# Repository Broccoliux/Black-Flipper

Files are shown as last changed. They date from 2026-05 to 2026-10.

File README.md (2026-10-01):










# FLIPPER BLACK

Flipper black is custom made hacking tool, it can out perfrom flipper Zero in almost every aspect. it have better and larger dsplay and have more power and range then flipper zero.

# Why i built this

I wanted a flipper zero but when i researched about it. i found out that just buying a Flipper Zero is almost useless, to unlock its full power we need to spend more $$, so i decided to build my own with everything in it, no external attachments needed.

# Zine

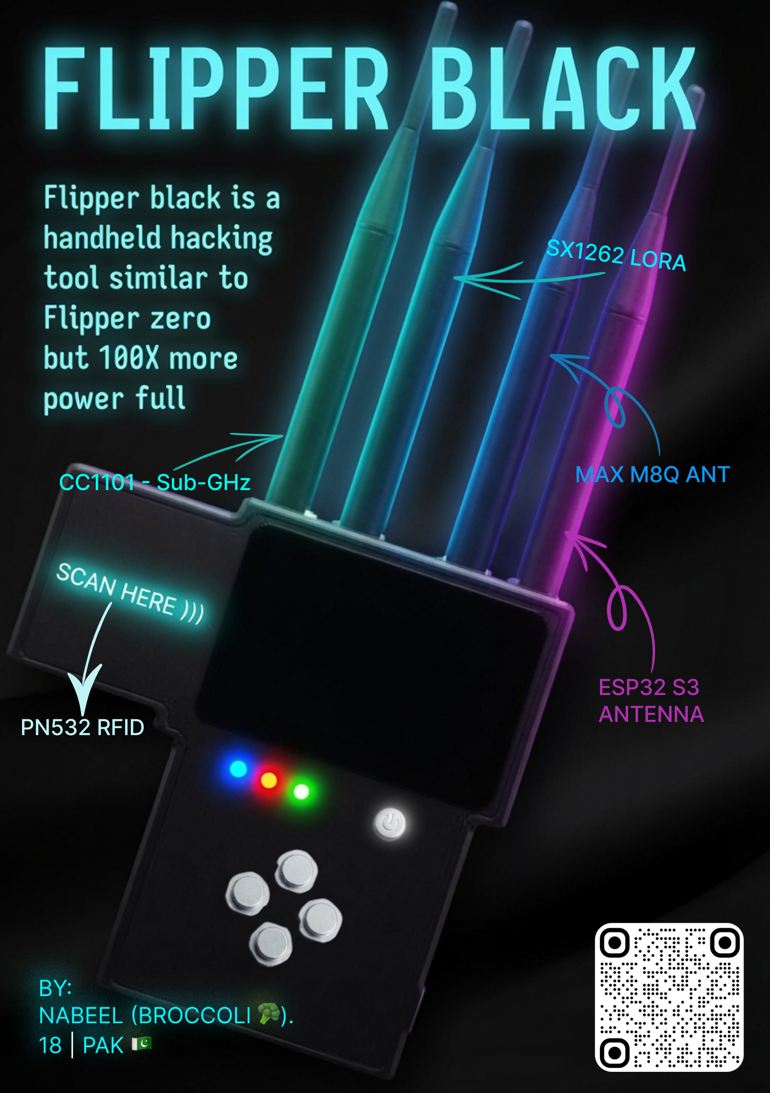
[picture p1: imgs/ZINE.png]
zine Preview


### CAD n Assembly

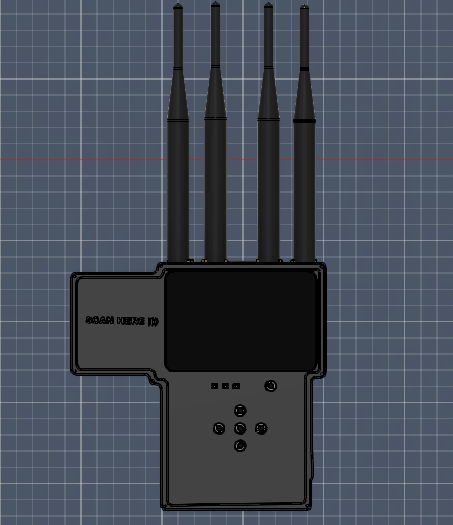
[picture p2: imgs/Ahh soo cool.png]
Assembled Device


### PCB

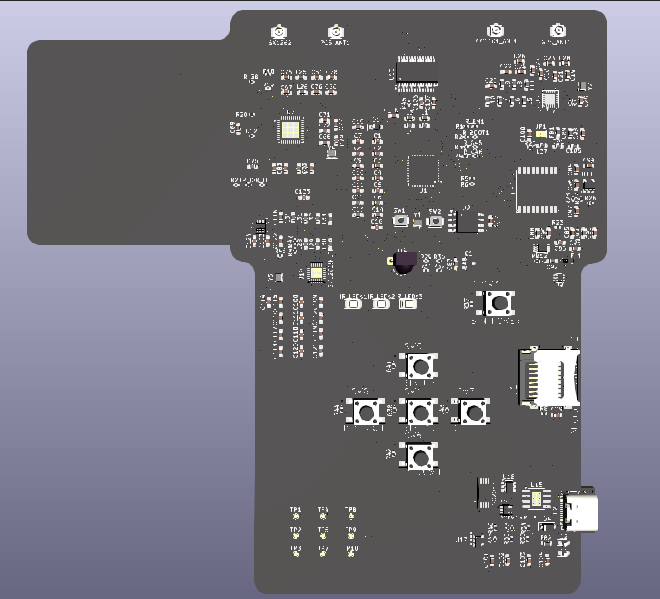
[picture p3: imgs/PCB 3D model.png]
PCB 3D Model


### Assembly

1. place the PCB in the enclosure.
2. secure the PCB with M2 screws.
3. Connect the display to FPC connector.
4. connect the antenna at top.
5. close with top enclosure and secure with screws.

## Features / components

- 4 layer PCB
- only ICs no modules used.
- Wi-Fi 802.11 built in
- BLE 5.0
- CC1101
- PN532
- MAX-M8Q
- Waveshare 3.5" IPS capacitive touchscreen
- W25Q128
- MicroSD
- TP4056
- TLV70018
- TXB0102
- Firmware based on ESP-IDF
- **Estimated BOM Cost:** $280–$350

## Firmware

**Status:** linked as a submodule

- Firmware is maintained in a differnt repository: https://github.com/fussdeek-del/Black-Flipper-firmware
- The firmware repository is included here as a git submodule at `external/firmware`.

To initialize the submodule locally after cloning:

```bash
git clone https://github.com/fussdeek-del/Black-Flipper
cd Black-Flipper
git checkout integrate/firmware-submodule-fix
git submodule update --init --recursive
```

To build the firmware (see the firmware repo):

```bash
cd external/firmware
idf.py build
```

 ### how to replicate

1. Get the gerber zip form repo and order the PCB from JLCPCB.
2. after receiving the PCB flash the firmware.
3. take the .step files from the repo and order the encloure.
4. here u go, u got custom flipper Black.

## Repository Structure
```

```text
Flipper-Black/
├── PCB/                        # KiCad project + Gerbers
├── CAD/                        # Fusion 360 enclosure (.step)
├── flipper black firmware/     # ESP-IDF firmware + architecture
├── Flipper Black guide pdfs/   # Documentation and guides
├── imgs/                       # Photos and renders
├── BOM/                        # Bill of Materials
└── README.md
```

### built by 

***broccoli 🥦***

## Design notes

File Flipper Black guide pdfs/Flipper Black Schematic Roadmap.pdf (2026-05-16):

# FLIPPER BLACK

# Complete Schematic Roadmap

This guide walks you through building the entire Flipper Black schematic in KiCad, chip by chip, step by step. Every connection is explained — what connects to what, why, and what label to use. Follow every chip section in order. Do not skip ahead.

WARNING: Web-verified against Espressif Hardware Design Guidelines (April 2026), CC1101 datasheet (TI), and SX1276 datasheet (Semtech). Always cross-check pin numbers against your exact chip datasheet before placing wires.

# Build order

### 1. ESP32-S3 — main MCU (start here)

### 2. W25Q128 — SPI flash (do immediately after MCU)

### 3. CC1101 — sub-GHz radio + RF matching network

### 4. SX1276 — LoRa transceiver + RF matching network

### 5. PN532 — NFC / RFID controller

### 6. MAX-M8Q — GPS + TLV70018 LDO + TXB0102 level shifter

### 7. Display + touch controller

### 8. IR TX / RX

### 9. Power system (TP4056 + DW01A + AP2112K + battery)

### 10. Buttons, test points, USB-C connector

CHIP 1 | ESP32-S3 | Main MCU — do this chip completely before anything else

The ESP32-S3 is the brain. Every other chip connects to it. You must finish this chip completely — every power pin, every decoupling cap, every strapping pin, the crystal, the flash SPI pins, the USB pins, and all net labels. Only then move to Chip 2.

## 1A — Power pins

The ESP32-S3 has multiple VDD pins. Each one needs its own 100nF decoupling capacitor placed directly on it. This is verified from the official Espressif Hardware Design Guidelines (April 2026).

Pin name | Pin number | What to connect | Cap required
VDD3P3_CPU | 46 | +3V3 power symbol | 100nF to GND
VDD3P3_RTC | 20 | +3V3 power symbol | 100nF to GND
VDD3P3 (analog) | 2, 3 | +3V3 power symbol | 100nF + 1uF + 10uF to GND — RF transmit causes current spikes
VDDA | 55, 56 | +3V3 power symbol | 100nF to GND each pin
VDD_SPI | 29 | +3V3 power symbol | 100nF + 1uF to GND — powers W25Q128 flash
GND | All GND pins | GND symbol | No cap needed
Thermal pad (bottom) | EP | GND symbol | Connect to large GND pad with minimum 9 vias in PCB layout

CRITICAL: Add a 10uF capacitor on VDD3P3 (pins 2 and 3). When ESP32-S3 transmits WiFi signals it draws sudden current spikes that collapse the power rail. The 10uF bulk cap prevents this. Verified from Espressif guidelines.

## 1B — Crystal (40 MHz — mandatory)

ESP32-S3 requires an external 40 MHz crystal. This is not optional. Without it the chip will not boot. Connect between XTAL_P and XTAL_N pins.

ESP32-S3 pin | Connect to | Value | Notes
XTAL_P (XIN) | Crystal pin 1 + load cap C1 to GND | Crystal: 40MHz SMD 3225 | Use NP0/C0G dielectric for load caps — NOT X7R or Y5V
XTAL_N (XOUT) | Crystal pin 2 + load cap C2 to GND | Crystal: 40MHz SMD 3225 | Load cap value matches crystal datasheet CL spec (typically 10pF)
XTAL_P trace | Series inductor R4 between XIN and crystal | 24nH inductor (initial value) | Reduces crystal harmonics affecting RF. Espressif recommends starting here.

TIP: Crystal load cap formula from Espressif: CL = (C1 x C2)/(C1+C2) + Cstray. If your crystal CL is 10pF and Cstray is ~2pF, use 22pF load caps. Check your crystal's datasheet CL value.

## 1C — Strapping pins (boot configuration)

Strapping pins are read at power-on to decide how the chip boots. Get these wrong and the chip won't start or will always enter download mode. These are verified from Espressif Hardware Design Guidelines.

GPIO | Net label | Connection | Why
GPIO0 | BOOT_BTN | 10k pull-up to +3V3. Tactile button to GND. | HIGH = normal boot. LOW = download/flash mode. Button lets you enter flash mode.
GPIO45 | GPIO45_STRAP | 10k pull-down to GND (resistor to GND). | Controls VDD_SPI voltage. LOW = 3.3V for W25Q128 flash (default needed).
GPIO46 | GPIO46_STRAP | 10k pull-down to GND (resistor to GND). | Must be LOW at boot. Do not leave floating.
CHIP_PU (EN) | EN_BTN | 10k pull-up to +3V3. Tactile button to GND. RC filter: 1uF cap to GND on this pin. | Enables chip when HIGH. Button pulls LOW to reset. RC filter prevents false resets.

WARNING: Do not add high-value capacitors on GPIO0. A large cap on GPIO0 keeps it LOW too long at startup, causing the chip to enter download mode every boot. The RC filter goes on CHIP_PU (EN) only, not on GPIO0.

## 1D — SPI net labels (signal pins to other chips)

These GPIO pins connect to other chips via net labels. Place the label on the GPIO pin. The matching label goes on the destination chip pin. This is how chips talk to each other without drawing wires across the sheet.

GPIO | Net label | Connects to | Direction
GPIO11 | SPI2_MOSI | CC1101 SI, PN532 MOSI (shared bus) | ESP32 sends data OUT
GPIO12 | SPI2_SCK | CC1101 SCLK, PN532 SCK (shared bus) | ESP32 sends clock OUT
GPIO13 | SPI2_MISO | CC1101 SO, PN532 MISO (shared bus) | ESP32 receives data IN
GPIO10 | SPI2_CS_CC1101 | CC1101 CSn only | ESP32 selects CC1101
GPIO9 | SPI2_CS_PN532 | PN532 NSS only | ESP32 selects PN532
GPIO35 | SPI3_MOSI | SX1276 MOSI, W25Q128 DI (shared bus) | ESP32 sends data OUT
GPIO36 | SPI3_SCK | SX1276 SCK, W25Q128 CLK (shared bus) | ESP32 sends clock OUT
GPIO37 | SPI3_MISO | SX1276 MISO, W25Q128 DO (shared bus) | ESP32 receives data IN
GPIO34 | SPI3_CS_SX1276 | SX1276 NSS only | ESP32 selects SX1276
GPIO33 | SPI3_CS_FLASH | W25Q128 /CS only | ESP32 selects flash
GPIO43 | ESP_UART_TX | TXB0102 level shifter B2 | GPS config commands OUT (add 100 ohm series resistor — boot conflict)
GPIO44 | ESP_UART_RX | TXB0102 level shifter B1 | GPS NMEA data IN
GPIO4 | CC1101_GDO0 | RF switch control + CC1101 GDO0 | TX/RX state signal from CC1101

GPIO | Net label | Connects to | Direction
GPIO5 | CC1101_GDO2 | CC1101 GDO2 | Packet interrupt from CC1101
GPIO21 | SX1276_DIO0 | SX1276 DIO0 | TX done / RX done interrupt from SX1276
GPIO47 | SX1276_RST | SX1276 RESET | ESP32 resets SX1276 — add 10k pull-up to +3V3
GPIO6 | PN532_IRQ | PN532 IRQ | Card detected interrupt from PN532
GPIO1 | I2C_SDA | Touch controller SDA | Bidirectional — add 4.7k pull-up to +3V3
GPIO2 | I2C_SCL | Touch controller SCL | Clock out — add 4.7k pull-up to +3V3
GPIO3 | TOUCH_IRQ | Touch controller IRQ | Touch interrupt IN
GPIO38 | IR_TX | NPN transistor base for IR LED | PWM output for IR transmission
GPIO39 | IR_RX | TSOP38238 IR receiver output | IR signal IN
GPIO7 | BATT_ADC | Voltage divider from battery | Analog IN — battery level monitoring
GPIO19 | USB_DN | USB-C connector D- | Fixed USB OTG pin — cannot change
GPIO20 | USB_DP | USB-C connector D+ | Fixed USB OTG pin — cannot change

TIP: GPIO33-37 are only available if you are NOT using octal PSRAM. Since Flipper Black uses external W25Q128 flash with no PSRAM, these GPIOs are free for SPI3.

CHIP 2 | W25Q128 | 16MB SPI Flash — do immediately after ESP32-S3

The W25Q128 is the firmware storage chip. It connects to ESP32-S3 via SPI3. You placed SPI3 net labels on ESP32-S3 already. Now you place matching labels on the W25Q128 pins.

## Pin connections

W25Q128 pin | Pin name | Net label | Notes
1 | /CS | SPI3_CS_FLASH | Active LOW. Add 10k pull-up to +3V3 — keeps chip deselected at power-on
2 | DO (MISO) | SPI3_MISO | Data out from flash to ESP32
3 | /WP | Tie to +3V3 via 10k pull-up | Write protect — pull HIGH to disable write protection
4 | GND | GND | Ground
5 | DI (MOSI) | SPI3_MOSI | Data in from ESP32 to flash
6 | CLK | SPI3_SCK | SPI clock from ESP32
7 | /HOLD | Tie to +3V3 via 10k pull-up | Hold pin — pull HIGH to disable hold function
8 | VCC | +3V3 | 100nF + 1uF decoupling caps to GND

TIP: After soldering, run 'esptool.py flash_id' to verify. Correct response: Manufacturer 0xEF, Device 0x4018. If you see 0xFF, there is a bad solder joint on one of the signal pins.

CHIP 3 | CC1101 | Sub-GHz Radio — includes RF matching network

The CC1101 is the most complex chip in terms of external components. It has a digital side (SPI interface to ESP32-S3) and an RF side (antenna matching network). Do the digital side first, then the RF side.

## 3A — Digital side (SPI + power)

CC1101 pin | Pin name | Net label / connection | Notes
1 | SCLK | SPI2_SCK | SPI clock from ESP32-S3
2 | SO (GDO1) | SPI2_MISO | SPI data out to ESP32-S3
3 | GDO2 | CC1101_GDO2 | Optional interrupt — connect to GPIO5. Add 10k pull-up to +3V3.
4 | DVDD | Leave isolated — connect only to C51 | DO NOT connect to your 3.3V rail. This is a regulated output FROM the chip. Connecting 3.3V here destroys it.
5 | DCOUPL | 100nF cap to GND only | Decoupling for internal regulator. No connection to power rail.
6 | GDO0 / CSn | GDO0: CC1101_GDO0 to GPIO4. CSn: SPI2_CS_CC1101 | Two separate pins. GDO0 is the TX/RX state indicator. CSn is chip select.
7 | GND | GND | Ground
8 | XOSC_Q1 | 26MHz crystal pin 1 + 15pF cap to GND | CC1101 needs 26MHz — NOT 40MHz
9 | AVDD | See power below | Analog VDD
10 | XOSC_Q2 | 26MHz crystal pin 2 + 15pF cap to GND
11 | AVDD | See power below
18 | GND | GND | Die attach pad — connect to GND with multiple vias
19 | GND | GND
20 | SI | SPI2_MOSI | SPI data in from ESP32-S3

### Power pins — CC1101 has 4 AVDD pins

Pin | Name | Connection | Decoupling
9 | AVDD | +3V3 | 100nF to GND
11 | AVDD | +3V3 | 100nF to GND
14 | AVDD | +3V3 | 100nF to GND
15 | AVDD | +3V3 | 100nF + 1uF to GND (this is the main RF power pin)

Also add a ferrite bead or small inductor (R171 in the datasheet schematic) in series with the power supply trace feeding all AVDD pins. This filters switching noise from entering the chip. Use a 600 ohm @ 100MHz ferrite bead.

## 3B — RF matching network (copy from datasheet)

The RF matching network sits between the CC1101's RF_P and RF_N pins and the antenna. Its job is to match the chip's output impedance to 50 ohms (the antenna standard). Use values from TI's datasheet Table 5 and DN013. Values differ per frequency band.

### Values for 433 MHz (ISM band — recommended for Flipper Black for maximum compatibility)

Component | Value | Location in circuit | Notes
L121 | 270nH | RF_P to balun | Multilayer OK for 433MHz
L122 | 270nH | RF_N to balun | Multilayer OK for 433MHz
L131 | 270nH | Balun inductor
L132 | 270nH | Balun inductor
C121 | 56pF | Matching cap | NPO/C0G dielectric — mandatory for RF
C122 | 56pF | Matching cap | NPO/C0G
C123 | 10pF | Matching cap | NPO/C0G
C124 | 12pF | Matching cap | NPO/C0G
C131 | 100nF | AVDD decoupling in RF section | +3V3 to GND, close to RF section
L123 | 39nH | Final matching inductor | Wire-wound for 433MHz
L124 | 39nH | Final matching inductor | Wire-wound
C125 | 100pF | DC blocking cap to antenna | Blocks DC, passes RF signal to antenna

### Values for 868 MHz (if you choose this band instead)

Component | Value | Notes
L121 | 5.6nH | Wire-wound required for 868MHz — not multilayer
L122 | 5.6nH | Wire-wound required
C121 | Not placed | Remove this component for 868MHz
C122 | Not placed | Remove this component for 868MHz
C123 | 5.6pF | NPO/C0G
C124 | 2.7pF | NPO/C0G
L131 | 8.2nH | Wire-wound balun
L132 | 8.2nH | Wire-wound balun
C131 | 100nF | Decoupling
C125 | 100pF | DC blocking to antenna

TIP: Use TI SmartRF Studio 7 (free download at ti.com/tool/SMARTRFSTUDIO) to generate exact CC1101 register values for your chosen frequency. Copy the output directly into firmware. Never calculate manually.

CRITICAL: Never use multilayer inductors for 868MHz or 915MHz RF matching. Their Q factor is too low at high frequency. Use wire-wound inductors (Murata LQW series or similar). For 433MHz multilayer is acceptable.

CHIP 4 | SX1276 | LoRa Transceiver — includes RF matching network

SX1276 is your LoRa radio. It has a 28-pin QFN package. Connect SPI3 from ESP32-S3, plus dedicated interrupt and reset pins. The RF output goes through a simple matching network to a U.FL connector or PCB trace antenna.

## 4A — SPI and control pins

SX1276 pin | Pin name | Net label / connection | Notes
1 | VDD_RXBPF | 100nF to GND | Internal LNA supply — decouple to GND only
2 | VDD_DCDC | Not connected (no connect marker) | Internal DC-DC — leave open unless using DC-DC mode
3 | VDD | + 3V3 | 100nF + 10uF to GND
5 | RFIO | RF output — to matching network | 50 ohm trace to matching network then U.FL
10 | NSS | SPI3_CS_SX1276 | Chip select. 10k pull-up to +3V3
11 | SCK | SPI3_SCK | SPI clock from ESP32
12 | MOSI | SPI3_MOSI | SPI data from ESP32
13 | MISO | SPI3_MISO | SPI data to ESP32
14 | RESET | SX1276_RST | Active LOW reset from GPIO47. 10k pull-up to +3V3.
15 | DIO0 | SX1276_DIO0 | TX done/RX done interrupt to GPIO21. MUST connect — do not float.
16 | DIO1 | Optional — connect to free GPIO or add no-connect marker | RX timeout interrupt
17 | DIO2 | No connect marker
18 | DIO3 | No connect marker
19 | DIO4 | No connect marker
20 | DIO5 | No connect marker
21 | GND | GND | Ground
28 | XTAL_2 | Crystal pin 2 + 10pF to GND | 32MHz crystal for SX1276
27 | XTAL_1 | Crystal pin 1 + 10pF to GND | 32MHz — different from ESP32's 40MHz

## 4B — RF matching network for 868 MHz

SX1276 RFIO pin connects to a simple pi-network matching circuit then to your antenna connector. The datasheet AN1200.13 provides these values.

Component | Value | Placement
L1 (RF choke) | 47nH | Between VDD and RFIO — blocks DC from antenna path

Component | Value | Placement
C1 | 10pF NPO | RFIO to GND — part of pi matching
C2 | Not placed (open) | Shunt cap — tune after testing
C3 (DC block) | 100pF NPO | Series between matching network and antenna
Antenna connector | U.FL SMD | 50 ohm impedance — route 50 ohm trace to here

TIP: Reference the Semtech SX1276 application note AN1200.13 (available at semtech.com) for the exact recommended matching network. For initial build just use the minimal circuit above — it works well enough to test range.

CHIP 5 | PN532 | NFC / RFID Controller

PN532 connects to SPI2 (same bus as CC1101, different CS pin). Interface mode is set permanently by two strapping pins using 0-ohm resistors — this is set before the board is made and cannot be changed in firmware.

## 5A — Interface mode selection (do this first)

PN532 has three interface modes. You must choose SPI mode. Set it by placing 0-ohm resistors on HSU0 and HSU1 pins. These resistors tie the pins to the correct voltage permanently.

Pin | Name | Connection for SPI mode | How to place it
HSU1 | Interface select 1 | Tie to GND via 0-ohm resistor | Place 0-ohm 0402 resistor between HSU1 and GND pad
HSU0 | Interface select 0 | Tie to +3V3 via 0-ohm resistor | Place 0-ohm 0402 resistor between HSU0 and +3V3 pad

WARNING: Do not hardwire HSU0/HSU1 directly to copper. Use 0-ohm resistors so you can change mode by reworking the resistors if needed. This was flagged in the improvement list.

## 5B — Pin connections

PN532 pin | Pin name | Net label / connection | Notes
1 | TXD / MISO | SPI2_MISO | SPI data out to ESP32 in SPI mode
2 | RXD / MOSI | SPI2_MOSI | SPI data in from ESP32 in SPI mode
3 | SCK | SPI2_SCK | SPI clock
4 | NSS | SPI2_CS_PN532 | Chip select. 10k pull-up to +3V3.
8 | IRQ | PN532_IRQ to GPIO6 | Interrupt output — card detected. 10k pull-up to +3V3.
VDD | VDD | +3V3 | 100nF + 1uF to GND
RSTPDN | Reset | 10k pull-up to +3V3. Optional GPIO for hard reset. | Active LOW reset
SVDD | SVDD | +3V3 | 100nF to GND — separate supply for RFID analog section
GND | GND | GND

## 5C — NFC antenna coil

PN532 needs an external PCB coil antenna. This is a rectangular spiral trace on your PCB, not a component you buy. The datasheet application note AN10609 gives the exact coil dimensions and tuning capacitor values. Draw it as a symbol in KiCad and connect pins LXIN and LXOUT to it via matching capacitors.

PN532 pin | Connect to
LXIN | NFC antenna coil pin 1 via tuning cap (C = 22pF typical, tune per AN10609)
LXOUT | NFC antenna coil pin 2 via tuning cap

## CHIP 6 MAX-M8Q + TLV70018 + TXB0102

GPS subsystem — three components treated as one

The GPS subsystem has three parts that must be designed together: the MAX-M8Q GPS chip (runs at 1.8V), the TLV70018 LDO (generates the 1.8V rail), and the TXB0102 level shifter (converts 1.8V UART to 3.3V for ESP32-S3). Do all three on the same schematic sheet.

## 6A — TLV70018 (1.8V LDO) — place this first

TLV70018 pin | Connection | Value
IN | +3V3 power symbol | 10uF + 100nF to GND on input
OUT | +1V8 power symbol — new power rail | 10uF + 100nF to GND on output
EN | Tie to IN (+3V3) via 100k pull-up | Always enabled — or connect to ESP32 GPIO for software control
GND | GND

CRITICAL: MAX-M8Q absolute maximum voltage is 1.9V. If you accidentally connect +3V3 to its VCC pin it is destroyed instantly and permanently. Label the 1.8V rail clearly as +1V8 so it cannot be confused with +3V3.

## 6B — MAX-M8Q GPS pin connections

MAX-M8Q pin | Pin name | Connection | Notes
VCC | +1V8 rail | 100nF + 1uF to GND — from TLV70018 output | NOT 3.3V — 1.8V only
VCC_IO | +1V8 rail | 100nF to GND separately | IO voltage — must match UART logic level
GND | GND | Multiple vias — short path
V_BCKP | Supercap (100mF) or coin cell (3V) | Maintains almanac between power cycles | Without this every startup is a 60s cold start. With it: 1s warm start.
TXD1 | GPS_TX_1V8 net label | Goes to TXB0102 A1 pin (1.8V side) | GPS sends NMEA sentences here
RXD1 | GPS_RX_1V8 net label | Goes to TXB0102 A2 pin (1.8V side) | GPS receives UBX config commands here
TIMEPULSE | Optional — no connect or GPIO | 1 pulse per second when satellite locked
RESET_N | 10k pull-up to +1V8 | Add optional GPIO for software reset | Active LOW
RF_IN | 50 ohm trace to U.FL connector | Passive ceramic patch antenna | Keep trace short. No ground pour under antenna area.

## 6C — TXB0102 level shifter pin connections

TXB0102 translates between 1.8V (GPS side) and 3.3V (ESP32 side). It has an A-side (1.8V) and a B-side (3.3V). OE pin must be tied HIGH to 3.3V — if it floats the chip outputs nothing.

TXB0102 pin | Connection | Notes
VCCA | +1V8 | 1.8V supply for GPS side. 100nF to GND.
VCCB | +3V3 | 3.3V supply for ESP32 side. 100nF to GND.
OE | Tie directly to VCCB (+3V3) | CRITICAL — must be HIGH. Floating OE = no data passes through.
A1 (1.8V side) | GPS_TX_1V8 (from MAX-M8Q TXD1) | GPS sends here
A2 (1.8V side) | GPS_RX_1V8 (to MAX-M8Q RXD1) | GPS receives here
B1 (3.3V side) | ESP_UART_RX (GPIO44 net label) | Translated signal to ESP32
B2 (3.3V side) | ESP_UART_TX (GPIO43 net label) | Translated signal from ESP32
GND | GND

WARNING: GPIO43 on ESP32-S3 is the default boot serial console TX pin. Add a 100 ohm series resistor between GPIO43 and the TXB0102 B2 pin. This prevents the boot console from fighting the GPS UART at startup.

## CHIP 7 Display + Touch Controller

3.5 inch IPS color touchscreen

The display uses SPI for pixel data and I2C for touch input. The exact pin names depend on your specific display module. Common controllers are ILI9488 or ST7796S for the display, FT6336 or CST816 for touch. Check your display's datasheet.

Signal | Net label | ESP32 GPIO | Notes
Display SPI MOSI | DISP_MOSI | GPIO15 | Data from ESP32 to display
Display SPI SCK | DISP_SCK | GPIO16 | Clock
Display CS | DISP_CS | GPIO17 | Chip select. 10k pull-up to +3V3.
Display DC | DISP_DC | GPIO18 | Data/Command select — HIGH=data, LOW=command
Display RST | DISP_RST | GPIO8 | Active LOW reset. 10k pull-up to +3V3.
Display VCC | +3V3 | — | 100nF + 10uF to GND
Touch SDA | I2C_SDA | GPIO1 | 4.7k pull-up to +3V3
Touch SCL | I2C_SCL | GPIO2 | 4.7k pull-up to +3V3
Touch IRQ | TOUCH_IRQ | GPIO3 | Interrupt — touch detected. 10k pull-up to +3V3.
Touch VCC | +3V3 | — | 100nF to GND
Backlight | Connect via NPN transistor or MOSFET to GPIO | — | PWM brightness control via transistor — do not connect LED directly to GPIO

CHIP 8 | IR TX / RX | Infrared transmitter and receiver

IR TX uses a high-power IR LED driven by an NPN transistor (2N2222 or MMBT2222 SMD). The transistor is needed because GPIO can only source 40mA — the IR LED needs more for good range. IR RX uses a demodulating receiver IC (TSOP38238) that handles filtering and demodulation automatically.

Component | Pin | Net label / connection | Notes
NPN transistor (MMBT2222) | Base | IR_TX (GPIO38) via 100 ohm resistor | Resistor limits base current
NPN transistor | Collector | IR LED array anode | Up to 3 IR LEDs in series
NPN transistor | Emitter | GND
IR LED array | Anode | Transistor collector | High-power 940nm IR LEDs (TSAL6400 or similar)
IR LED array | Cathode | GND | 33 ohm current limiting resistor in series
TSOP38238 receiver | OUT | IR_RX (GPIO39) | Output is demodulated IR signal
TSOP38238 | VCC | +3V3 | 100nF + 10uF to GND — datasheet requires good decoupling here
TSOP38238 | GND | GND

CHIP 9 | Power System | TP4056 + DW01A + AP2112K + battery connector

The power system has four parts: the TP4056 charges the battery from USB-C. The DW01A protects against overcharge, overdischarge, and short circuit. The AP2112K converts battery voltage to clean 3.3V. Design these in order.

## 9A — TP4056 battery charger

TP4056 pin | Connection | Notes
VCC | VBUS (+5V from USB-C) | 100nF to GND
GND | GND
PROG | Resistor to GND | Sets charge current. 1.2kohm = 1A charge current.
TEMP | 10k pull-up to VCC | No thermistor — just pull up
CHRG | LED + resistor to GND (optional) | Charge indicator LED — shows when charging
STDBY | LED + resistor to GND (optional) | Standby indicator LED — shows charge complete
BAT | Battery positive via DW01A | Output to battery — goes through DW01A first

## 9B — DW01A protection IC + FS8205 dual MOSFET

DW01A works together with a dual N-channel MOSFET (FS8205A) to physically disconnect the battery under fault conditions. They must be used together.

DW01A pin | Connection
VDD | Battery positive (after TP4056 BAT pin)
GND / CS | Battery negative + current sense resistor to GND
OC | FS8205A gate 1 — controls overdischarge cutoff
OD | FS8205A gate 2 — controls overcharge cutoff

## 9C — AP2112K-3.3 LDO regulator

AP2112K pin | Connection | Notes
VIN | Battery positive (from DW01A protected output) | 1uF + 10uF to GND on input
GND | GND
EN | Tie to VIN via 100k pull-up | Always enabled. Or connect to GPIO for software power control.
VOUT | +3V3 power rail | 10uF + 100nF to GND on output. This feeds every chip on the board.
VOUT (bulk) | Add 100uF electrolytic to GND | Handles large transient current spikes from WiFi and RF TX

## 9D — Battery connector

Connector pin | Connection
Pin 1 (positive) | TP4056 BAT and DW01A VDD
Pin 2 (negative) | GND via DW01A / FS8205A current sense path

TIP: Use a JST-PH 2.0mm 2-pin connector for the battery. This is the standard for 18650 and LiPo cells. Orient it on the PCB so polarity is obvious — mark + and - on the silkscreen.

CHIP
10

## Buttons + Test Points + USB-C

Final connections

## 10A — BOOT and EN buttons

Both buttons must be accessible from outside the aluminum enclosure without disassembly. Route them to pinhole buttons in the enclosure wall or to a header accessible from outside.

Button | Connects between | Net label | Notes
BOOT button | GPIO0 and GND | BOOT_BTN | GPIO0 already has 10k pull-up from Chip 1 strapping pins
EN (reset) button | CHIP_PU and GND | EN_BTN | CHIP_PU already has 10k pull-up and 1uF RC filter from Chip 1

## 10B — Test points (mandatory for debugging raw chips)

Test points are bare 1mm copper pads with no solder mask. You probe them with a scope or multimeter. Add one on every critical net. Raw QFN chips at 0.5mm pitch are impossible to probe directly.

Test point | Net to connect | Why
TP1 | SPI2_MOSI | Debug CC1101 and PN532 data
TP2 | SPI2_SCK | Debug SPI2 clock
TP3 | SPI2_MISO | Debug SPI2 response
TP4 | SPI3_MOSI | Debug SX1276 and flash data
TP5 | SPI3_SCK | Debug SPI3 clock
TP6 | ESP_UART_TX | Debug GPS UART output
TP7 | ESP_UART_RX | Debug GPS NMEA input
TP8 | +3V3 | Probe main power rail
TP9 | +1V8 | Probe GPS power rail
TP10 | GND | Reference probe point

## 10C — USB-C connector

USB-C pin | Connection | Notes
VBUS | VBUS rail to TP4056 VCC | Add ESD protection diode (USBLC6-2SC6) on VBUS — protects from USB spikes
D+ | USB_DP (GPIO20) | Fixed USB OTG pin on ESP32-S3
D- | USB_DN (GPIO19) | Fixed USB OTG pin on ESP32-S3
CC1, CC2 | 5.1k resistors to GND each | Required for USB-C power negotiation — without these chargers may not provide power
GND | GND | Shield and signal ground

## Final checklist before moving to PCB layout

Check | What to verify
ERC clean | Run Inspect > Electrical Rules Check. Zero errors. All warnings reviewed and justified.
Every VCC pin has decoupling | Open each chip symbol. Confirm 100nF on every VCC pin.
Every CS pin has pull-up | 10k pull-up to +3V3 on: CC1101 CSn, PN532 NSS, SX1276 NSS, W25Q128 /CS
Strapping pins correct | GPIO0 pull-up + button. GPIO45 pull-down. GPIO46 pull-down. EN pull-up + RC + button.
PN532 HSU pins set | HSU1 to GND via 0-ohm. HSU0 to +3V3 via 0-ohm.
TXB0102 OE pin HIGH | OE tied directly to VCCB (3.3V). Not floating.
MAX-M8Q on 1.8V only | +1V8 symbol on MAX-M8Q VCC and VCC_IO. Never +3V3.
Crystal values correct | ESP32-S3: 40MHz. CC1101: 26MHz. SX1276: 32MHz. All different.
No connect markers placed | Every intentionally unused pin has an X marker
Net labels consistent | SPI2_MOSI on ESP32-S3 GPIO11 matches SPI2_MOSI on CC1101 SI exactly — same spelling, same case
All footprints assigned | Tools > Assign Footprints — no components with missing footprint

Flipper Black Schematic Roadmap · Web-verified May 2026 · For personal use only

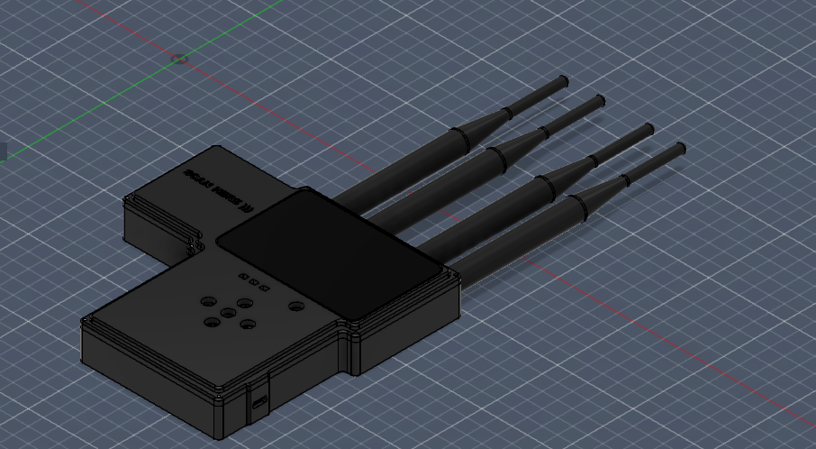
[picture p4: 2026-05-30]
imgs/final design.png

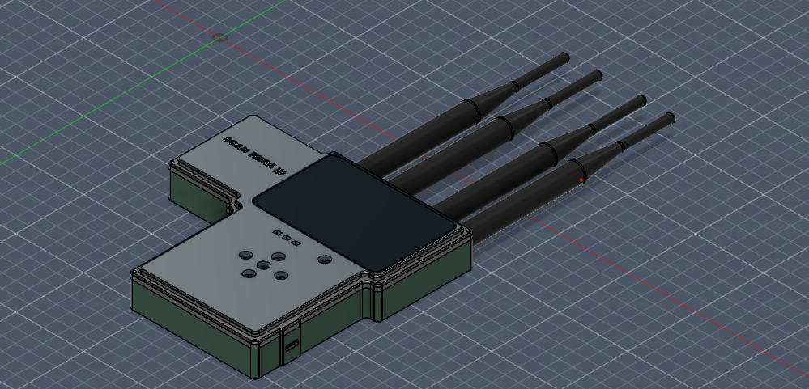
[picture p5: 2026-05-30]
imgs/RAW design.png

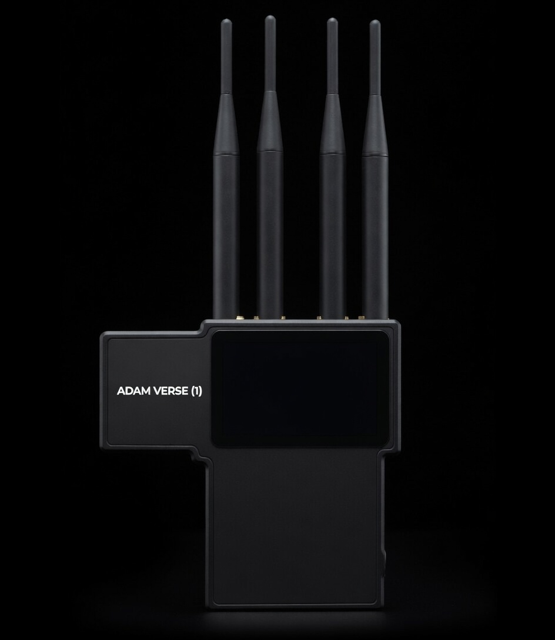
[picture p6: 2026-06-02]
imgs/polished.jpg

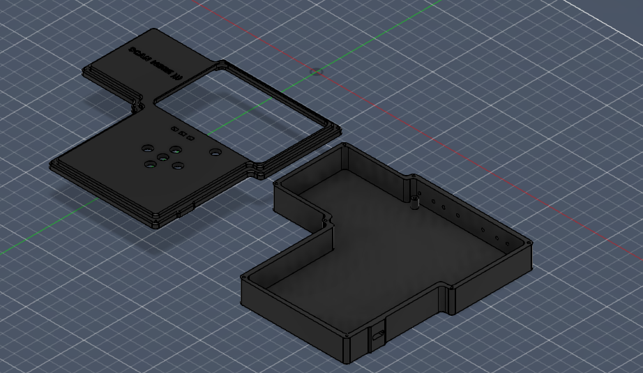
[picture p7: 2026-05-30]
imgs/both bodies.png

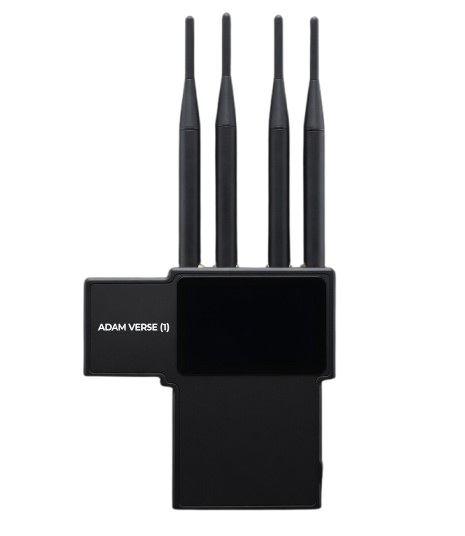
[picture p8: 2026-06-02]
imgs/removed BG.png

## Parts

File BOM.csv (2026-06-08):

Reference | Qty | Value | link | cost | min Qty can buy | Total
C1,C2,C6,C7,C8,C17,C18,C67,C68,C69,C70,C71,C75,C84,C86,C87,C94,C96,C97,C98,C99,C100,C107,C109,C113,C121 | 26 | 100nf | https://www.aliexpress.com/item/32371454429.html | $1.5 | 100
C3,C16,C101 | 3 | 0.1uf | https://www.aliexpress.com/item/1005005653862475.html | $1.5 | 100
C4,C95,C102,C103,C104,C106 | 6 | 10uf | https://www.aliexpress.com/item/1005005653862475.html | $2 | 100
C5,C9,C72,C85,C108,C_EN1 | 5 | 1uf | https://www.aliexpress.com/item/1005007137284660.html | $1 | 100
C10,C11,C19,C20,C21,C22,C23,C24,C28 | 9 | 18pf | https://www.aliexpress.com/item/1005007137284660.html | $1 | 100
C12 | 1 | 1.8pf | https://www.aliexpress.com/item/1005007137284660.htmll | $1 | 100
C13 | 1 | 1.2pf | https://www.aliexpress.com/item/1005007137284660.html | $1 | 100
C14,C25 | 2 | 1.0pf | https://www.aliexpress.com/item/1005007137284660.html | $1 | 100
C15,C26,C27 | 3 | 1.5pf | https://www.aliexpress.com/item/1005007137284660.html | $1 | 100
C74,C78,C80,C92,C119,C73 | 6 | 22pf | https://www.aliexpress.com/item/1005007137284660.html | $1 | 100
C76,C77,C79,C81 | 4 | 220pf | https://www.aliexpress.com/item/1005007137284660.html | $1 | 100
C82,C91,C116,C122 | 4 | 1nf | https://www.aliexpress.com/item/1005007137284660.html | $1 | 100
C83,C105 | 2 | 100pf | https://www.aliexpress.com/item/1005007137284660.html | $1 | 100
C88 | 1 | 47pf | https://www.aliexpress.com/item/1005007137284660.html | $1 | 100
C89 | 1 | 10pf | https://www.aliexpress.com/item/1005007137284660.html | $1 | 100
C90,C93 | 2 | 10nf | https://www.aliexpress.com/item/1005007137284660.html | $1 | 100
C110 | 1 | 470nf | https://www.aliexpress.com/item/1005007137284660.html | $1 | 100
C111,C112,C118,C120,C123 | 5 | 10pf | https://www.aliexpress.com/item/1005007137284660.html | $1 | 100
C114 | 1 | 6.8pf | https://www.aliexpress.com/item/1005007137284660.html | $1 | 100
C115,C125 | 2 | 8.2pf | https://www.aliexpress.com/item/1005007137284660.html | $1 | 100
C117,C124 | 2 | 5.66pf | https://www.aliexpress.com/item/1005007137284660.html | $1 | 100
CC1101_ANT1,GPS_ANT1,PCB_ANT1,SX1262_ANT (U.FL) | 4 | 50ohm | https://www.aliexpress.com/item/1005010015902109.html | $5 | 4
D1 | 1 | TPESD5V0L2 | https://jlcpcb.com/partdetail/TECHPUBLIC-TPMG85XP/C52817258 | $1 | 10
D2,D3 | 2 | LED | https://www.aliexpress.com/item/1005006207219959.html | $3.5 | 200
D4 | 1 | MBR1020VL | https://www.lcsc.com/product-detail/C191986.html | $0.93 | 10
FB1,FB2 | 2 | BLM21PG221SN1D | https://www.lcsc.com/product-detail/C85840.html | $0.92 | 20
FL1 | 1 | SAFFB1G58KA0F0A | https://www.lcsc.com/product-image/C91647.html | $1 | 10
IR_LEDs1,IR_LEDs2,IR_LEDs3 | 3 | 940nm | https://www.aliexpress.com/item/1005003330154455.html | $5 | 20
J2 | 1 | DISP_3.5_WAVESHARE | https://www.aliexpress.com/item/1005008868165133.html | $23 | 1
L1 | 1 | 2nH 500mA | https://jlcpcb.com/partdetail/Sunlord-SDWL1608C24NJSTFM01/C408735 | $0.3 | 10
L2 | 1 | 24nH | https://www.aliexpress.com/item/1005003077524611.html | $2.7 | 50
L3,L4 | 2 | 2.7nH | https://www.aliexpress.com/item/1005003077524611.html | $2.7 | 50
L5,L6,L7,L8,L32 | 5 | 27nH | https://www.aliexpress.com/item/1005003077524611.html | $2.7 | 50
L9,L10 | 2 | 47nH | https://www.aliexpress.com/item/1005003077524611.html | $2.7 | 50
L11 | 1 | 23nH | https://www.aliexpress.com/item/1005003077524611.html | $2.7 | 50
L25,L26 | 2 | 220nH | https://www.aliexpress.com/item/1005003077524611.html | $2.7 | 50
L27 | 1 | 5.6nH | https://www.aliexpress.com/item/1005003077524611.html | $2.7 | 50
L28,L33 | 2 | 18nH | https://www.aliexpress.com/item/1005003077524611.html | $2.7 | 50
L29,L30 | 2 | 15nH | https://www.aliexpress.com/item/1005003077524611.html | $2.7 | 50
L31,L34 | 2 | 22nH | https://www.aliexpress.com/item/1005003077524611.html | $2.7 | 50
P1 | 1 | JST-2pin | https://www.aliexpress.com/item/1005009002970396.html | $1.7 | 10
P2 | 1 | USB_C_Plug_USB2.0 | https://www.aliexpress.com/item/1005008805157100.html | $2.9 | 10
Q1 | 1 | MMBT2222A | https://www.lcsc.com/product-detail/C83939.html | $0.7 | 50
Q2 | 1 | FS8205A | https://www.win-source.net/products/detail/fortune/fs8205a.html | $0.4 | 20
R1,R2,R3,R4,R5,R_I0,R_I1 | 7 | 0R | https://www.aliexpress.com/item/1005004350795351.html | $0.5 | 100
R6 | 1 | 499R | https://www.aliexpress.com/item/1005004350795351.html | $0.5 | 100
R7,R24,R26,R27,R34,R18,R19,R23,R28,R45,R46,R_38,R_BOOT1,R_EN1,R_G45,R_G46 | 15 | 10K | https://www.aliexpress.com/item/1005004350795351.html | $0.5 | 100
R20,R22,R25,R37,R38,R41,R42,R43,R44 | 9 | 10R | https://www.aliexpress.com/item/1005004350795351.html | $0.5 | 100
R21,R35,R36 | 3 | 1K | https://www.aliexpress.com/item/1005004350795351.html | $0.5 | 100
R29,R30,R32 | 3 | 33R | https://www.aliexpress.com/item/1005004350795351.html | $0.5 | 100
R31,R47,R48 | 3 | 100R | https://www.aliexpress.com/item/1005004350795351.html | $0.5 | 100
R33 | 1 | 1.2K | https://www.aliexpress.com/item/1005004350795351.html | $0.5 | 100
R39 | 1 | 100K | https://www.aliexpress.com/item/1005004350795351.html | $0.5 | 100
R40 | 1 | 5.1K | https://www.aliexpress.com/item/1005004350795351.html | $0.5 | 100
SW3,4,5,6,7,8 | 6 | BUTTONS smd | https://www.aliexpress.com/item/1005005845072975.html | $0.7 | 10
SW1,2 | 2 | IC BUTTONS | https://www.aliexpress.com/item/1005011940846103.html | $0.5 | 20
TP1,2,3,4,5,6,7,8,9 | 5 | TP HOLES | "" | Free | 9
U1 | 1 | ESP32-S3 | https://www.lcsc.com/product-detail/C2913192.html | $5 | 1
U2 | 1 | W25Q128JVS | https://www.lcsc.com/product-detail/C97521.html | $3.5 | 1
U3 | 1 | CC1101 | https://www.lcsc.com/product-detail/C29953.html | $2 | 1
U7 | 1 | PN5321A3HN | https://jlcpcb.com/partdetail/NXPSemicon-PN5321A3HN_C10655/C28925 | $11 | 1
U8 | 1 | MAX-M8Q | https://www.lcsc.com/product-detail/C6898733.html | $8.5 | 1
U9 | 1 | MASW-007221 | https://jlcpcb.com/partdetail/MACOM-MASW_007221TR3000/C17492491 | $10 | 15
U10 | 1 | BGA725L6 | https://www.digikey.com/en/products/detail/infineon-technologies/BGA725L6E6327FTSA1/3911483 | $1 | 3
U11 | 1 | TLV70018_SOT23-5 | https://www.lcsc.com/product-detail/C79924.html | $1.5 | 5
U12 | 1 | TXB0102DCU | https://www.lcsc.com/product-detail/C22469961.html | $2 | 5
U13 | 1 | MCP23017x-x-SS | https://www.lcsc.com/product-detail/C506653.html | $2 | 1
U14 | 1 | TSOP382xx | https://www.lcsc.com/product-detail/Infrared-Receivers_VISHAY_TSOP38236_TSOP38236_C5139.html | $1 | 5
U15 | 1 | TP4056 | https://www.lcsc.com/product-detail/Battery-Management-ICs_TPOWER-TP4056_C382139.html | $2 | 5
U16 | 1 | PESD5V0L4UG,115 | https://www.lcsc.com/product-detail/C80694.html | $2 | 5
U17 | 1 | AP2112K-3.3 | https://www.lcsc.com/product-detail/C51118.html | $1.5 | 5
U18 | 1 | DW01A | https://www.lcsc.com/product-detail/C351410.html | $1.5 | 20
U19 | 1 | SX1262IMLTRT | https://www.lcsc.com/product-detail/C191341.html | $4 | 1
U20 | 1 | PE4259 | https://www.lcsc.com/product-detail/C470892.html | $1 | 1
Y1 | 1 | 40MHz SMD 3225 | https://www.lcsc.com/product-detail/C5380316.html | $1 | 10
Y2 | 1 | 26 MHz SMD | https://www.lcsc.com/product-detail/C5380316.html | $2 | 5
Y4 | 1 | 27.120 MHz SMD | https://www.lcsc.com/product-detail/crystals_jwt-cn4027m12006t8188114_C2932960.html | $1.5 | 5
Y5 | 1 | 32 MHz SMD | https://www.lcsc.com/product-detail/C113671.html | $0.5 | 5
ANTENNAs | 1 | 2.4GHz WiFi Antenna U.FL IPEX | https://www.aliexpress.com/item/1005007038434546.html | $5 | 1
ANTENNAs | 1 | 868MHz LoRa Antenna U.FL IPEX | https://www.aliexpress.com/item/33046299234.html | $5 | 1
ANTENNAs | 1 | 868MHz 915MHz Sub-GHz Antenna U.FL | https://www.aliexpress.com/item/1005007273656690.html | $3 | 1
ANTENNAs | 1 | 868MHz U.FL IPEX LoRa Antenna | https://www.aliexpress.com/item/1005005275069992.html | $3 | 1
ANTENNA connector | 4 | U.FL IPEX to SMA Female pigtail 10cm | https://www.aliexpress.com/item/1005001622659327.html | $5 | 10
mounting nuts | 20 | 2.1mm | https://www.aliexpress.com/item/1005005523229681.html | $2 | 20
PCBA | 1 | above cost wont be added if i go PCBA |  | $120 | 5
3D case | 1 | maybe go for local printer |  | $30 | 1
 |  |  |  |  |  | $280 | NOTE: if i go for PCBA price will drop to $180.

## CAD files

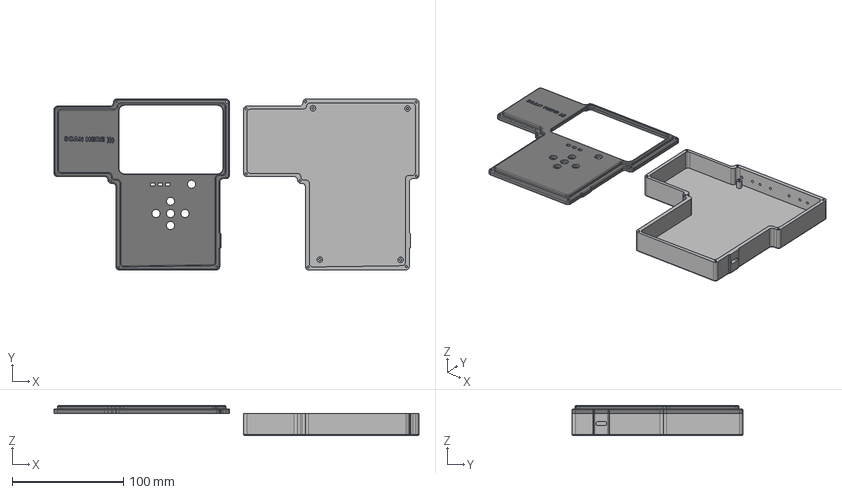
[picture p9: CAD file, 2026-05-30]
CAD/full step file_.step
327.5 x 153.3 x 27.0 mm

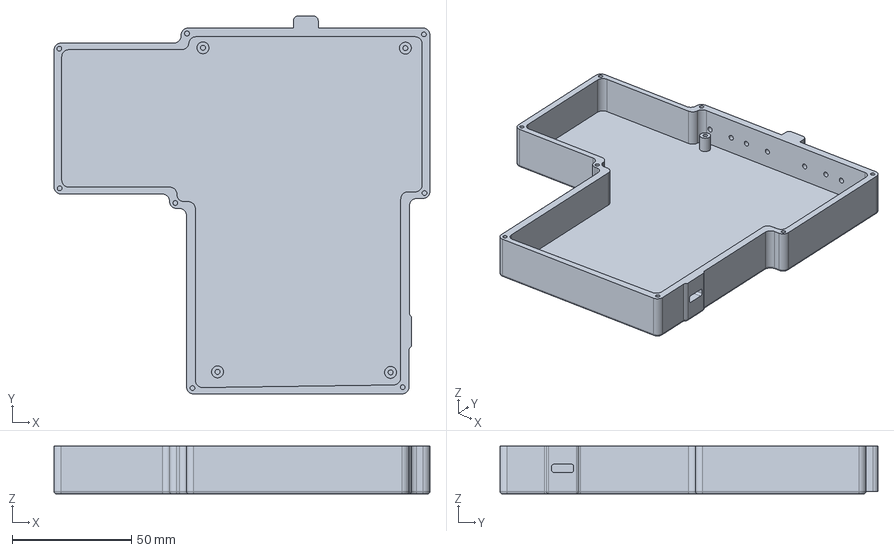
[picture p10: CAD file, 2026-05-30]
CAD/lower body.step
157.5 x 158.3 x 20.0 mm

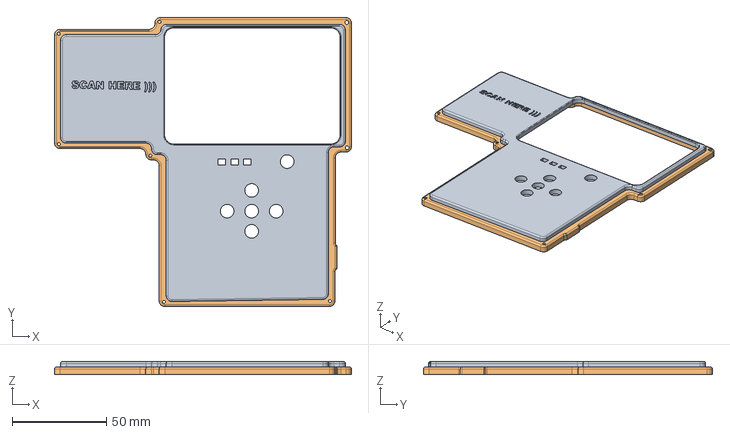
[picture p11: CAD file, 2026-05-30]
CAD/Upper body.step
157.5 x 153.3 x 7.00 mm

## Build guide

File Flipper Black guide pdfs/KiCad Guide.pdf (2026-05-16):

# FLIPPER BLACK

## Reading Datasheets + KiCad 10 Schematic Guide

From zero to complete schematic — step by step

This guide teaches you two things: how to extract everything you need from a chip datasheet, and how to turn that into a correct schematic in KiCad 10. It is written specifically for Flipper Black. Every concept is explained before you are asked to do it.

## Contents

Part 1 | How to Read a Datasheet for Schematic Design
Part 2 | KiCad 10 — Project Setup and Interface
Part 3 | Adding Symbols and Creating Custom Ones
Part 4 | Wiring the Schematic Correctly
Part 5 | Power Symbols, Decoupling Caps, and Net Labels
Part 6 | Hierarchical Sheets — Splitting a Big Design
Part 7 | Running ERC and Fixing Errors
Part 8 | Flipper Black — Schematic Order of Operations

## Part 1 — How to Read a Datasheet for Schematic Design

A datasheet is a chip manufacturer's official document. It tells you everything you need to wire the chip correctly. Most beginners skip it. That is why their boards don't work. This section teaches you what to extract from any datasheet before opening KiCad.

## The 7-step reading order

Every datasheet is different but every useful datasheet has these seven sections. Read them in this order every time.

### 1 Step 1 — Typical

Application Circuit

Go here first. It is a complete reference schematic showing the chip connected with all its required external components. Copy it exactly to start. This is your baseline. Only deviate when you have a specific reason.

### 2 Step 2 — Features list

(page 1)

Bullet list of what the chip can do. Confirm: frequency range, interface (SPI/I2C/UART), voltage range, and any specific feature you are counting on. If it is not in this list, the chip does not have it.

### 3 Step 3 — Pin

description table

Lists every pin by name, number, direction (input/output/power), and function. This is the most-used page in the whole document. You will return to it constantly while drawing the schematic.

### 4 Step 4 — Absolute

maximum ratings

The limits you must NEVER exceed — max voltage, max current, max temperature. Exceeding any of these kills the chip instantly or slowly. Design to the Recommended Operating Conditions, not the maximum ratings.

### 5 Step 5 — Electrical

characteristics

The actual operating specs — supply current, logic thresholds, timing. Confirms your LDO output voltage is compatible and your GPIO logic levels match.

6 | Step 6 — Register map | For configurable chips like CC1101 and SX1276. A table of every internal register, its address, bits, and default value. You will use this when writing firmware, not schematic design.

### 7 Step 7 — Errata

| document | A SEPARATE document from the manufacturer. Official list of known silicon bugs. Always download and read errata before finalizing your design. Espressif, TI, and NXP all publish errata.

## What to extract and write down before KiCad

Before drawing a single wire in KiCad, extract these four things from each chip's datasheet and write them in a notebook or text file:

What to extract | Where to find it | Why you need it
Supply voltage (VCC range) | Electrical characteristics | Confirm your 3.3V rail is in range

What to extract | Where to find it | Why you need it
All VCC and GND pin numbers | Pin description table | Every VCC pin needs a decoupling cap in schematic
Interface pins (MOSI/MISO/SCK/CS or SDA/SCL or TX/RX) | Pin description table | Map to your GPIO pin assignment document
Required external components | Typical application circuit | Crystal, decoupling caps, pull-ups — all listed here
Logic voltage level | Electrical characteristics / Absolute max | Confirms if level shifting is needed (e.g. GPS at 1.8V)
Active HIGH or active LOW pins | Pin description table | CS, RESET, IRQ — direction matters for pull-up/pull-down

## Decoupling capacitors — what they are and why they are mandatory

Every chip draws sudden bursts of current when it switches states. Without decoupling caps, these bursts cause voltage dips on the power rail that corrupt data and crash chips. Decoupling caps are local energy reservoirs — tiny batteries sitting right next to each chip.

Cap value | Purpose | Placement
100 nF (0.1 uF) ceramic X5R/X7R | High-frequency decoupling — absorbs fast current spikes | One per every VCC pin, as close as physically possible
1-10 uF ceramic X5R | Mid-frequency bulk storage | One per chip, slightly further away from VCC pin
100 uF electrolytic | Low-frequency bulk on main power rail | Near LDO output, one per board

CRITICAL: NEVER use Y5V dielectric capacitors for decoupling. At 3.3V operating voltage, a Y5V '100nF' cap becomes approximately 18nF — it is basically useless. Always use X5R or X7R dielectric. The dielectric code is in the part description on LCSC.

## How to read the CC1101 datasheet — worked example

Open the CC1101 datasheet from TI (ti.com/lit/ds/symlink/cc1101.pdf). Here is exactly what to extract:

What you find | Value | What it means for your schematic
Typical application circuit | Page 1 of datasheet | Copy the crystal + decoupling cap arrangement exactly
VCC range | 1.8V to 3.6V | 3.3V rail is fine
XTAL frequency | 26 MHz required | Buy a 26MHz crystal — not 27MHz, not 25MHz
Interface | SPI active LOW CS | CS pin needs 10k pull-up to 3.3V
GDO0 pin | Configurable output | Connect to ESP32 GPIO — used for TX/RX state signal to RF switch
GDO2 pin | Configurable output | Connect to ESP32 GPIO — used for packet received interrupt
Package | QFN-20, 4x4mm | Select QFN-20 footprint in KiCad

TIP: For CC1101: use TI SmartRF Studio 7 (free download from ti.com) to generate the register values for your target frequency. Never calculate CC1101 register values manually — the formula involves fractional PLLs and is error-prone.

## Part 2 — KiCad 10 Setup and Interface

KiCad 10 was released April 2025. Download it from kicad.org. The official documentation for KiCad 10 is at docs.kicad.org/10.0/en/. Always use the official docs — they are accurate and complete.

IMPORTANT: One experienced designer noted KiCad 10 has some bugs in early releases. If you encounter instability, KiCad 9 is fully stable and the workflow is identical. Everything in this guide applies to both versions.

## First time setup

1 | Install KiCad 10 | Download from kicad.org. On Windows, run the installer. On first launch, select 'Install default libraries' — this gives you thousands of ready-made symbols and footprints.
2 | Create a new project | File > New Project. Give it a name: 'Flipper_Black'. KiCad creates a folder with a .kicad_pro file, a .kicad_sch schematic file, and a .kicad_pcb board file. Keep all files in this folder.
3 | Open Schematic Editor | Double-click the .kicad_sch file in the project window, or click the Schematic Editor button. This is where you will spend most of your time.
4 | Set page size | File > Page Settings. Set paper size to A3 or A2 — Flipper Black has many components and needs space. Add your name and project name in the title block.

## The KiCad 10 schematic editor — what each part does

Area | What it is | How to use it
Canvas | The white drawing area where your schematic lives | Scroll to zoom. Middle-click drag to pan. G key to grab and move.
Right toolbar | Place tools — symbols, wires, labels, power ports | Click or use keyboard shortcuts (A = add symbol, W = wire, P = power port)
Left toolbar | View tools — zoom, grid, highlight | Mostly use keyboard shortcuts instead
Properties panel | Shows properties of selected item | Click any component to see and edit its reference, value, footprint
Net Inspector (Inspect menu) | Lists all nets and connections | Use to verify every pin is connected before ERC

## Essential keyboard shortcuts — memorize these

Key | Action
A | Add symbol (place a component)
W | Draw wire
P | Add power port (VCC, GND, +3V3)

Key | Action
L | Add net label
R | Rotate selected item
G | Grab and move (keeps connections)
E | Edit properties of selected item
Delete | Delete selected item
Ctrl+Z | Undo
Ctrl+S | Save
Ctrl+D | Duplicate
F | Flip (mirror) selected item
Scroll wheel | Zoom in/out
Middle click drag | Pan the canvas

## Part 3 — Adding Symbols and Creating Custom Ones

A symbol in KiCad is the schematic representation of a component — a box with pins. It is NOT the physical footprint. The symbol shows logical connections. The footprint shows physical pads on the PCB. You assign a footprint to each symbol later.

## Adding a symbol from the built-in library

1 | Press A | Opens the 'Choose Symbol' dialog. A search box appears.

### 2 Search by name or part

| number | Type 'ESP32' or 'CC1101' or 'resistor'. KiCad searches all installed libraries. For generic passives, search 'R' for resistor, 'C' for capacitor.

### 3 Select the correct

| symbol | Click it once to preview. Verify the pin names match your datasheet. Click OK.
4 | Place it on the canvas | Move mouse to position, click to place. Press Escape when done placing.
5 | Assign footprint | Double-click the symbol > Properties > Footprint field. Click the browse button. Search for the correct package (e.g. QFN-20).

TIP: For Flipper Black chips, most symbols exist in the default KiCad library. Search 'ESP32-S3', 'CC1101', 'SX1276', 'PN532'. If not found, use SnapEDA (snapeda.com) to download a KiCad symbol + footprint pair for free.

## Creating a custom symbol (when the chip is not in the library)

If a chip is not in KiCad's library or SnapEDA, you create it manually in the Symbol Editor. This takes 15-30 minutes per chip. Here is the process:

1 | Open Symbol Editor | In the KiCad project window: Tools > Symbol Editor. Or from the schematic editor: Place > Add Symbol > Symbol Editor button.
2 | Create new library | File > New Library. Name it 'Flipper_Black'. Save it in your project folder. This keeps your custom symbols with your project.
3 | Create new symbol | File > New Symbol. Enter the chip name (e.g. 'MAX-M8Q'). Set reference prefix to 'U'.

### 4 Add pins from

| datasheet | Place > Add Pin. For every pin in the datasheet pin table: set pin name, pin number, and direction (Input/Output/Bidirectional/Power). Pin numbers must match the datasheet exactly.
5 | Draw the body | Place > Add Rectangle. Draw a box around the pins. Pins on left = inputs. Pins on right = outputs. Power pins on top/bottom.
6 | Save and use | File > Save. Return to schematic editor. Press A, search your chip name. It appears in your custom library.

CRITICAL: Pin numbers in KiCad must match the physical pin numbers in the datasheet exactly. If pin 1 in KiCad is connected to a different net than pin 1 on the physical chip, your board will not work. Always cross-check.

## Part 4 — Wiring the Schematic Correctly

Wiring in KiCad connects pins together to form nets. A net is a named group of connections — like 'SPI2_MOSI' or 'GND'. Every wire you draw is part of a net. There are three ways to connect pins in KiCad.

## Three ways to connect pins

Method | When to use it | How
Direct wire (green line) | Pins that are physically close to each other on the canvas | Press W, click pin, route to destination, click to end
Net label | Pins far apart, or same signal on different parts of schematic — like SPI2_MOSI going to 3 chips | Press L, type label name (e.g. SPI2_MOSI), place on wire end. Any two labels with the same name are connected.
Power port | VCC, GND, +3V3 — global power nets that every chip shares | Press P, search 'GND' or '+3V3', place on power pin

IMPORTANT: For Flipper Black, use net labels for ALL SPI signals, UART signals, and inter-chip connections. Do NOT run long wires across the schematic — the canvas becomes unreadable. Label everything.

## Naming net labels — follow this convention for Flipper Black

Net | Label name
SPI2 MOSI (CC1101 + PN532 + Display) | SPI2_MOSI
SPI2 MISO | SPI2_MISO
SPI2 SCK | SPI2_SCK
SPI3 MOSI (SX1276 + Flash) | SPI3_MOSI
SPI3 MISO | SPI3_MISO
SPI3 SCK | SPI3_SCK
CC1101 chip select | CC1101_CS
SX1276 chip select | SX1276_CS
PN532 chip select | PN532_CS
Display chip select | DISP_CS
GPS UART to ESP32 | GPS_TX
GPS UART from ESP32 | GPS_RX
LoRa interrupt | LORA_DIO0
RF switch control | RF_SW_CTRL

TIP: Consistent naming prevents ERC errors and makes your schematic readable. Every label name must match exactly — 'SPI2_MOSI' and 'spi2_mosi' are different nets in KiCad. Use all caps with underscores.

## Part 5 — Power Symbols, Decoupling Caps, and Net Labels

Power symbols are special symbols in KiCad that represent global power nets. Every component that connects to GND uses the same GND power symbol. Every component that connects to 3.3V uses the same +3V3 symbol. They are automatically connected to each other without drawing wires.

## Power symbols used in Flipper Black

Symbol name | Voltage | Connected to
+3V3 | 3.3V | ESP32-S3 VCC, CC1101 VCC, SX1276 VCC, PN532 VCC, display, IR, most chips
+1V8 | 1.8V | MAX-M8Q VCC and VCC_IO only — comes from TLV70018 LDO
GND | 0V / Ground | Every chip GND pin, decoupling cap bottom rail, LDO GND
VBAT | 3.7V nominal (battery) | TP4056 input, DW01A, battery positive terminal
+VBUS | 5V USB input | TP4056 VIN from USB-C connector

## How to place decoupling caps in KiCad correctly

1 | Identify all VCC pins | Look at the chip symbol. Every pin labeled VCC, VDD, AVCC, DVCC needs its own 100nF decoupling cap.

### 2 Place capacitor symbol

| next to chip | Press A, search 'C', place a capacitor symbol directly beside the chip's VCC pin on the canvas. Keep it visually close — this reminds you to place it physically close on the PCB later.

### 3 Connect top of cap to

| same VCC net | Draw a short wire from capacitor top pin to the chip VCC pin. Then add a +3V3 power symbol on that wire.

### 4 Connect bottom of cap

| to GND | Add a GND power symbol to the capacitor bottom pin.
5 | Set capacitor value | Double-click cap > Properties > Value field. Type '100nF'. For bulk caps type '10uF'.
6 | Set capacitor footprint | Footprint field > Browse > search '0402'. For 10uF use '0603'.

Flipper Black decoupling cap count: ESP32-S3 has 9 VCC pins = 9x 100nF caps. CC1101 has 2 VCC pins = 2x 100nF. SX1276 = 1x 100nF + 1x 10uF. PN532 = 1x 100nF. MAX-M8Q = 2x 100nF. Total: approximately 20-25 decoupling caps on the schematic. This is normal.

## Part 6 — Hierarchical Sheets — Splitting a Big Design

Flipper Black has 8+ chips. Putting everything on one schematic sheet makes it unreadable. KiCad supports hierarchical sheets — a parent sheet with sub-sheets, each containing one section of the design. This is exactly how the Flipper Zero hardware schematics are organized.

## Recommended sheet structure for Flipper Black

Sheet name | Contents
Main (top level) | Sheet hierarchy overview, power rails, connectors only
MCU | ESP32-S3, W25Q128 flash, crystal, all decoupling, strapping pins, BOOT/EN buttons
Radio_SubGHz | CC1101, 26MHz crystal, RF switch, PA amplifier, antenna connector
Radio_LoRa | SX1276, antenna connector, decoupling
NFC | PN532, NFC antenna coil, decoupling, HSU strapping
GPS | MAX-M8Q, TLV70018 1.8V LDO, TXB0102 level shifter, TCXO, antenna connector, backup supercap
Display | 3.5in IPS display connector, touch controller, backlight driver
Power | TP4056 charger, DW01A protection, AP2112K LDO, battery connector, USB-C connector

## How to create hierarchical sheets in KiCad 10

### 1 Place a hierarchical

sheet block

In the main schematic: Place > Add Hierarchical Sheet. Draw a rectangle on the canvas. Give it a name (e.g. 'MCU') and a filename (e.g. 'mcu.kicad_sch').

2 | Add hierarchical pins | These are the connection points between sheets. Right-click the sheet block > Import Sheet Pin. Or add pins manually via Place > Add Hierarchical Pin.
3 | Open the sub-sheet | Double-click the sheet block. A new schematic editor opens for that sheet. Draw the circuit here.

### 4 Connect sheets with

| global labels | Use Place > Add Global Label for signals that cross multiple sheets (like GND, +3V3, SPI2_MOSI). Global labels with the same name connect automatically across all sheets.

### 5 Navigate between

| sheets | Click the sheet block to enter it. Press Escape or use the breadcrumb at the top to go back to parent.

TIP: Study the Flipper Zero open source schematics at github.com/flipperdevices/flipperzero-firmware — they use hierarchical sheets and are an excellent real-world reference for how to organize a complex design like Flipper Black.

## Part 7 — Running ERC and Fixing Errors

The Electrical Rules Check (ERC) is KiCad's automated checker. It scans your schematic for logical errors — unconnected pins, conflicting drivers, missing power flags. Always run ERC and fix all errors before moving to PCB layout. Zero errors and zero warnings is the goal.

## How to run ERC

In the schematic editor: Inspect > Electrical Rules Checker > Run ERC. Or click the bug icon in the toolbar. Errors appear as red markers on the schematic. Click any error to jump to it.

## Common ERC errors and how to fix them

Error | What it means | How to fix
Pin unconnected | A pin has no wire, label, or power symbol connected | Add a wire to the net, or add a 'No Connect' marker (press Q) if the pin is intentionally unused
Power pin not driven | A power net (VCC, GND) has no source | Add a PWR_FLAG symbol to the net. This tells KiCad the power comes from an external source.
Conflicting net names | Two different labels connected to the same wire | Delete one label or rename to match
Pin connected to pin (no net) | Two component pins connected directly with no net name | Add a net label to the wire between them
Duplicate reference | Two components with the same reference (U1 U1) | Tools > Annotate Schematic > Annotate All. This auto-assigns unique references.
Hierarchical pin not connected | A sheet pin has nothing connected to it inside the sub-sheet | Open the sub-sheet and add a hierarchical label matching the pin name

IMPORTANT: PWR_FLAG is not optional. KiCad requires at least one PWR_FLAG on every power net (+3V3, GND, +1V8, VBAT). Without it, ERC throws 'Power pin not driven' on every chip. Place PWR_FLAG symbols near your LDO outputs and battery connector.

## Annotate schematic before ERC

Before running ERC, always annotate: Tools > Annotate Schematic > Annotate All > OK. This assigns sequential reference designators (U1, U2, C1, C2...) to all components. Without annotation, ERC cannot identify components correctly.

## Part 8 — Flipper Black Schematic — Order of Operations

This is your exact build sequence. Do not jump ahead. Each step must be complete before the next one starts.

### 1 Day 1 — Project setup

+ MCU sheet

Create KiCad project. Set up 8 hierarchical sheets. Draw the ESP32-S3 sheet first — place chip symbol, all decoupling caps (9x 100nF + bulk caps), 40MHz crystal with load caps, CHIP_PU pull-up, GPIO0 pull-up, BOOT button, EN button, W25Q128 flash with full SPI connections. Add all net labels for every GPIO. Run ERC on this sheet alone before continuing.

2 | Day 2-3 — Power sheet | Draw TP4056 charger circuit from datasheet typical application. Add DW01A protection. Add AP2112K-3.3 LDO. Add TLV70018 1.8V LDO for GPS. Add battery connector (JST-PH 2-pin). Add USB-C connector. Add all PWR_FLAG symbols. Run ERC.

### 3 Day 4 — CC1101 + RF

| switch sheet | Draw CC1101 from TI typical application circuit. Add 26MHz crystal + load caps. Add PA amplifier. Add PE4259 RF switch with GPIO control from CC1101 GDO0. Add SMA antenna connector. Add all SPI net labels matching MCU sheet. Run ERC.

### 4 Day 5 — SX1276 LoRa

| sheet | Draw SX1276 from Semtech typical application. Add decoupling. Connect DIO0 to interrupt GPIO. Add SPI net labels for SPI3 bus. Add SMA antenna connector. Run ERC.

### 5 Day 6 — PN532 NFC

| sheet | Draw PN532. Hardwire HSU1=GND and HSU0=VCC via 0-ohm resistors (not copper) for SPI mode selection. Add NFC antenna coil circuit from NXP application note AN10609 — this is a matched LC network, copy it exactly. Run ERC.
6 | Day 7 — GPS sheet | Draw MAX-M8Q. Add TLV70018 1.8V LDO. Add TXB0102 level shifter (OE tied HIGH to 3.3V, A-side to 1.8V GPS, B-side to 3.3V ESP32 UART). Add 26MHz TCXO from u-blox approved list. Add U.FL antenna connector. Add backup supercap on V_BCKP. Run ERC.

### 7 Day 8 — Display + IR

| sheet | Draw 3.5in display connector with SPI + I2C touch pins. Draw IR TX circuit: GPIO > NPN transistor (2N3904) > IR LED array. Draw IR RX: TSOP38238 demodulator with decoupling. Run ERC.

### 8 Day 9 — Full ERC +

| review | Run ERC on all sheets. Zero errors, zero warnings. Review every net label — confirm SPI2 labels on MCU sheet match SPI2 labels on CC1101 and PN532 sheets. Confirm SPI3 labels match SX1276 and flash. Review pin assignment document against schematic.

### 9 Day 10 — Footprint

| assignment | Double-click every component. Assign correct KiCad footprint: QFN-56 for ESP32-S3, QFN-20 for CC1101, LCC-18 for MAX-M8Q, etc. Verify pad counts match pin counts.

## After schematic is complete

Step | Action
Generate netlist | File > Export > Netlist. This file links your schematic to the PCB editor.
Update PCB from schematic | Open PCB editor. Tools > Update PCB from Schematic. All footprints appear as a pile — ready for placement.
Push to GitHub | git add, git commit, git push. Commit after every major section is complete.

Flipper Black KiCad Guide · Built for broccoli · May 2026

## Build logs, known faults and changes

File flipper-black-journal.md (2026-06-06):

# Flipper Black — Journal Export

- Exported at: 2026-06-05T20:07:18Z
- Project ID: 3136
- Entries: 37

## Entry 1
- ID: 6292
- Author: Broccoli
- Created At: 2026-05-09T17:35:42Z

### Content

the idea is clear and i have discussed this briefly with AI, now i am going to reserch about it online.

i   asked AI to make me research guide for me to get to know about every component in brief.

today i will be researching about components and there date sheet and will be making complete resources pack. so other can do it too.

I read the complete guide and there was few flaw init, i fixed it and make a new one now it is better, i will publish this as a starter guide if i get approved. 

i started to read the documentation for ESP32-S3 but its so complex lol. i think i have to use yt, now i planned to do everything by learing in schmetaic its pinout annd all that. so i wont face difficulty when building real sch.

guide is quite well written:


### Recording Links

- https://lookout.hackclub.com/api/media/01dea53e-8ce1-4ca9-9e17-c1c4466beec7/video.mp4

## Entry 2
- ID: 6457
- Author: Broccoli
- Created At: 2026-05-10T17:45:23Z

### Content

i started building the schematic and asked grok to help me out, now i cant find the pins specific pins, damn 


i think i have added the wrong symbol,
the symbol was correct add the pins were just hidden, i learn something new, now i know how to make new symbol and how to edit existing,

i have  started the schematic, i am not sleeping until i completely do U1


now i cannot find the the symbol for crystal this is used in data sheet 



### Recording Links

- https://lookout.hackclub.com/api/media/b85c7b65-b434-45b8-a111-ab4c05d4d322/video.mp4

## Entry 3
- ID: 6486
- Author: Broccoli
- Created At: 2026-05-10T20:18:28Z

### Content

i add some GPIO and its late night and i am soo sleepy so i am not able to do anything rn, 



added these two, tomorrow will it be completed and idk, lol

### Recording Links

- https://lookout.hackclub.com/api/media/d1b45e72-dfa9-4ddf-a6d9-d8a2c8623f04/video.mp4

## Entry 4
- ID: 6681
- Author: Broccoli
- Created At: 2026-05-11T22:44:45Z

### Content

I did so much today, but i forget to journal time by time, it was so hard i read full data sheet for W25Q128 External SPI Flash, so wont have any problems in futures, although i didn't understand most of it, LOL

thi is where i am rn, and i sure 100% that there are tons on mistakes in it, fuuu



### Recording Links

- https://lookout.hackclub.com/api/media/6dcefee1-05d9-4115-9123-08830c5cda25/video.mp4

## Entry 5
- ID: 6850
- Author: Broccoli
- Created At: 2026-05-12T22:58:58Z

### Content

today i only did this 


i am not able to lock in but i want i wants to do 100+ hours

i hope will be able to do it.

also started CC1101 Sub-GHz Transceiver.

these shits are to confusing for me

### Recording Links

- https://lookout.hackclub.com/api/media/6b067424-1454-40de-aea1-dc4c8c94b23b/video.mp4

## Entry 6
- ID: 7001
- Author: Broccoli
- Created At: 2026-05-13T22:38:26Z

### Content

IDk whats going own, i am so confused 😕 and felling to low, today, i think i need motivation, cuz i am going to slow, i have to finish this and prepare for exams. 
Wish me luck.

anyway, now i am going to do C1101 lasd day i added its symbol and foot paint not i have to connect it with MCU>

CC1101 complete finally, 




nxt components is SX1276 — LoRa Transceiver

lets see how difficult this will be.

i am fisrst time working with raw die chips and i am excited cuz they look soo damn cool, 




these looks soooooooo gud gud, love it,

i edited the pins of lora SX1276 LOL, i hope this will work< i did it cuz the GND were hidden
Before: 



damn i add the pin where the wire cannot be connected.
shit, it not working, 

i messed up it losses it origin.

now i have to make this all, even i just have to copy its still hard, look how difficult it looks 


i am struggling to find this symbol from the data sheet, but i cant find it so far, maybe i should use similar alternatives 


i did some work today, but i think my pace is too slow, i need ot speed up, i have to prepare for exams too. i think i should stop reading the full data sheet, they do help me understand the things more wise but they take to much time , i will be just reading the enough to move furter, and i will deep dive into this data sheets once my exams completes,

### Recording Links

- https://lookout.hackclub.com/api/media/1d3fb55a-dcf7-4d6a-b005-df830736ec6e/video.mp4

## Entry 7
- ID: 7208
- Author: Broccoli
- Created At: 2026-05-15T04:38:33Z

### Content

last day i started the schematic of SX1276 i did some work on it last day, and today i will be completing it, ASAP

i am trying to make it clean as much as i can, 


there is sand Strom rn here, and electricity is out, idk my goal was to do 5hrs a day to complete this, but last day i was only able to do 20min.

### Recording Links

- https://lookout.hackclub.com/api/media/17be0681-b43a-4718-9c15-16a9c6913801/video.mp4

## Entry 8
- ID: 7273
- Author: Broccoli
- Created At: 2026-05-15T15:51:06Z

### Content

so i have completed the SX1276 and now i have sanity checked it its is good to goo now, 



this ws more complex then ESP32 S3 raw chip

### Recording Links

- https://lookout.hackclub.com/api/media/a69c23f2-e49d-4085-a823-3b469f4a7d86/video.mp4

## Entry 9
- ID: 7389
- Author: Broccoli
- Created At: 2026-05-16T09:36:26Z

### Content

I was doing ERC and there are so lame error that i rey to solve they weren't bif problems but just power pins, but when i saw them they were normal but erc keep showing the errors. 

 see i have connected the GND with GND but its still shows the error, 


see these all need 3.3V power i added ad named VDD33 and it is showing error 


same here 


one error resolved, 


all error are resolved now expect a new one a gnd pin i not working i dk why, its is connected with GND but still.

i am ignoring that error the GND one, cuz i have connected it with GND and it is properly connected so that might me a KICAD glitch, cuz i am using ki cad 10 i heard it has too many bus init, 

finally we have error after ignoring GND error, 



now i  am going to read the datasheet for  PN532, yes i know i said i wont read full data sheets but i think this is better to read full.

i also think i have to make this one below in PCB with routing idk why exactly but as per slack and AI they say u have to make it 



finally i found the real datasheet the offical one using VPN, i hopw it has refrance schematic 

i am going to read it no matter what, i dont need any confusion later, 

i have have read enough to start working now i am understanding datasheets much better i think i must read datasheets before starting  any component work.

### Recording Links

- https://lookout.hackclub.com/api/media/a0a59fff-7697-4cb9-8fd4-d5e9bb25d5b5/video.mp4

## Entry 10
- ID: 7475
- Author: Broccoli
- Created At: 2026-05-16T18:58:17Z

### Content

so i have made quite good progress, today not that much but i fell in so many problems, first i didn't found the right symbol then when i found it i didn't found the reference schematic, so i tried doing it myself using just datasheet, cuz i had alredy read the data sheet before so i didn't had that much problem like before but there were still problems, like mode selection i read this part (Mode Selection), but i didn't knew the what pins so i asked the AI the Grok said something diff and claude said something diff, at the end i sated so many ai and did a manually researching then i found out these pins are for MODE selection.


i also labeled it, 

also added crystal


one thing i forgot to mention and that is i added the sub connection to all SPI pins, 


### Recording Links

- https://lookout.hackclub.com/api/media/8a5da96b-be1b-49ac-bbaa-774dbebcd7f0/video.mp4

## Entry 11
- ID: 7502
- Author: Broccoli
- Created At: 2026-05-16T21:50:28Z

### Content

i think i have completed the PN532, but i am not sure 100%, 
but i am gonna sleep now, tomorrow i will be do deep verification. so sleep for now, LOL.



### Recording Links

- https://lookout.hackclub.com/api/media/40ee881b-e1fa-4999-b051-54c2a23ebe41/video.mp4

## Entry 12
- ID: 7592
- Author: Broccoli
- Created At: 2026-05-17T12:01:43Z

### Content

well well i have finally completed the PN532, there were only few minor mistakes that i solved. so there is how it looks rn.










cant believe i made it all by my self,

now its time for next component and that is (NEO-6M — GPS Receiver ) time to lock in. 

shit i forgot to pause the recording for about 15-18min
anyone who is reviewing this, plzz cut 20mins, 

change in the plan, i am not gonna be using (NEO-6M — GPS Receiver) instead i will be using (MAX-M8Q) why, cuz i researched and the (NEO-6M — GPS Receiver) is too old its is from 2009. and now that efficient and cost is also similar. 

ohh price is not similar, MAX-M8Q is quite expansive, 


i will be using first one, its good for V0

i think 15-22$ are worth for this 


vooo 


so now i haved completed the datasheet of MAX-M8Q, and this was the best datasheet it wasn't long for 100+ pages its was short and things was explain so well that it was best for newbies like me.

i cannot find the reference schematic. this is what i found. so far and it dont looks the onw i should follow.


1 more component almost done i will complete it today, and its brothers, i ma king subsystem for this. 




### Recording Links

- https://lookout.hackclub.com/api/media/9905b6f2-952d-47c2-9209-0201959074d4/video.mp4

## Entry 13
- ID: 7684
- Author: Broccoli
- Created At: 2026-05-17T20:51:03Z

### Content

so, i have finally completed the SUBSYSTEM with these components MAX-M8Q + TLV70018 + TXB0102. i just reverified it correct and ERC has 0 errors 


i am trying to make it as much clean as i can: so thats why i am using lines to make separation between component's,



i know this is hard to read but, for sanity check i will send them complete file,

so the next thing is to add Display + Touch
Controller
3.5 inch IPS color touchscreen

### Recording Links

- https://lookout.hackclub.com/api/media/f7a36159-ce63-4892-ba31-b6fc5ee6157f/video.mp4

## Entry 14
- ID: 7846
- Author: Broccoli
- Created At: 2026-05-18T20:08:53Z

### Content

now i have added the display and connected GPIOs, and i have also added extra GPIOs (MCP23017x) because i was low on GPIos . i have connected the 4 main pins of display to ESP32 S3 and other are connected to extra GPIOs. 




i think i should have started placing components on PCB from the start so wont get confused and I with it will be more professional, but anyway, i will find a way out somehow, 

the next thing according to PDF is IR TX / RX

IDK what will they for for my display but lets see how it goes, maybe i ditch it if i dont have any cool factor in it, as much i know my researching, this is used to catch and transmits, 

i tried to see how components will look in PCB with components so far, but my PC said hell nah, and kicad stopped responding and that why i am writing this journal, cuz time is money and i should not waste it. 

It looks so organized to me. hehe looks cool.


i just tried again opening PCB but its stopped again.

it already looks so cool, i haven't use any rae chips before this is first time and it looks so professional, but still i haven't added footprints for caps and R, when i will all components PCB will be looking messy, but i will manage to make it compact and professional.






now its time to do sum reserch.

i have now also competed TP4056. this is only 1st part of power system. 


i think my schematic will be completed by tomorrow, (inshallah) then there will be more harder part, the traces and routings although the routings are not hard for me, i did 720 routes in my last project, but the thing is this time it will be 4 layer and and there antennas too and i dont know how to use them..

now  i have completed the power system, there might be few mistakes init i will do it tomorrow, also i have done USB C connector (USB_C_Plug_USB2.0) this was easy i dont think it will have any mistakes, 



now the next things are left are Boot buttons and test point, i dont have any concept of test points , i will figure it out tomorrow, inshallah tomorrow schematic will be finalized and we will be ready to move to next PHASE, the PCB.

byeeee

### Recording Links

- https://lookout.hackclub.com/api/media/0b853449-c402-461d-908d-2826a5d0eb59/video.mp4

## Entry 15
- ID: 8036
- Author: Broccoli
- Created At: 2026-05-19T20:52:43Z

### Content

well well well, i have officially finished the schematics, its has zero ERC errors. and it looks pretty professional too.

i have completes the power system tomorrow, and i mentioned that in next journal i will complete the schematic. although i have more idea to add init. but for now the my main idea is completely done, maybe i will add few things init and, then routing, routings gonna be soo though, WHY i have 5 antennas and according to my online friend and i am deep-fried.

and i have also added the power points too. for easy debugging.



ohh yea i forgot to mention that i have also added the 6 extra buttons, even we have touch display, we still need them, and i will be placing them as a real flipper zero have. 





### Recording Links

- https://lookout.hackclub.com/api/media/640f401d-2613-45da-8eb5-41c81cbe7690/video.mp4

## Entry 16
- ID: 8201
- Author: Broccoli
- Created At: 2026-05-20T19:11:10Z

### Content

**last day i completed the schematics and send it for sanity check there was only minor corrections that i did. and its done, now today i tried to assign the footprints but couldn't, i was doing 5 hrs a day but from last 2 days i am only doing 1 hr a day. need motivation.**



### Recording Links

- https://lookout.hackclub.com/api/media/d3bb365c-60ef-4ecb-9d59-7ffe4d3ad490/video.mp4

## Entry 17
- ID: 8387
- Author: Broccoli
- Created At: 2026-05-21T22:56:04Z

### Content

so i have almost assigned all the foot prints, only BGA725L6 left, and i was struggling to add it and and i found it, its day 3 of unmotivated me. today i again only did 2 hrs only, tomorrow i will do 7hrs+ no matter what, 

anyway tomorrow i will also start PCB and all that, 

i wonder my system is always on edge i just added the LIB of BGA725L6 and KICAD stops responding. lol



its official now, i have finally added all the footprints. now lets see hpw pcb looks in mess

damn too messy



but i have errors it day any 5 components still dont have there footprints, i will do it tmro

### Recording Links

- https://lookout.hackclub.com/api/media/3c2641e0-c497-4a5f-9229-ba8886ddf768/video.mp4

## Entry 18
- ID: 8554
- Author: Broccoli
- Created At: 2026-05-22T22:47:55Z

### Content

so today i finally did 7hrs, i back with fire in meeeee, a day before yesterday i send my schematic PDF for sanity check my mentors and he told me in detail that with is not right, so first i asked my Claude skill to help me understand what it says so i can have better picture in my head,

mentor said the following:

```
disconnect this power net highlighting in first image, your low pass filter won't do anything if it's tied on both sides
why are you using the same saw filter on both high and low frequency? while ideally it'd work on high frequency (868MHz), it'll act as a bandpass filter and destroy your low frequency functionality (434MHz)
just know that given how relatively high the frequency you're working with is (and therefore very low component values and tolerances), you'll need several iterations of testing different values in your sx1276 network. tiny tiny changes in your board layout will create parasitics and make pretty much all of that circuitry useless unless you're willing to iterate on your design!
you might also consider switching to the more modern sx1262, which allows you to use johanson's ipd line to skip these components entirely
same thing goes for the cc1101 circuitry
i'd suggest following the reference board designs very closely and make sure your pcb stackup matches
not sure what specific display you're working with but you'll probably need some more decoupling on the display connector
what's the purpose of the barrel jack path on the gps switch?
you should really have a dc blocking capacitor on the AI pin of the lna. this removes dc bias which could potentially damage the lna!
the labels on either side of the level shifter (u12) are the same, you should have one be 3.3 level and one be 1.8 level for it to do anything
you might want to consider adding a ferrite bead or rc filter between the usb shield and ground. this way, it will only be connected to the computer with dc, and the rf from you various modules won't go straight into the computer
you seem to be using vdd33 and +3.3v interchangeably but i don't see them tied together at one point
```

now that i have solved all the errors he told me i went to re assign footprints, it was hell it was hard to find the correct symbols, after thaat i did it again again the checking if PCB looks alright or not and the footprint is acceptable or not. after assigning the footprint i started the separating the components to ensure better connectivity and structure, i will be going with 4 LAYER PCB, 

i cannot explain how i am happy to build this thing. this will be defiantly be considered as hard tier project.

### Recording Links

- https://lookout.hackclub.com/api/media/6a56511f-7de2-4242-8f30-38e67deaf7ea/video.mp4

## Entry 19
- ID: 8600
- Author: Broccoli
- Created At: 2026-05-23T06:22:16Z

### Content

after completing the corrections by the mentors i give PDF him again and he told most things are good just need lil more things need correction, he told me to use SX1262 instead of SX1276, 

designing new lora


### Recording Links

- https://lookout.hackclub.com/api/media/93f37fe7-4ada-4ca5-a964-e892de736428/video.mp4

## Entry 20
- ID: 8770
- Author: Broccoli
- Created At: 2026-05-24T02:26:55Z

### Content

i have almost completed the new SX1262, as per mentors and AI it is better and provide better performance. i really hope this will be better, it good it have less components init.  

now i am going to get the best values possible for CAPS RESISTORS AND INDUCTORS, i get the best performance.

now i have completed the full SX1262, with all values assigned and connected. 



now i am going to assign the footprint to the newly added components, after that i have to open my last project schematic the broccoli board to see what footprint is used for USB C cuz rn it is not rendering and looks fishy 

now i have placed my all components assembled so compactly, this is not my final design i just did this to make all components close to each other as much them can, for final PCB design i will be going something like voke talke, i genrated an img from grok to get an idea for design and its crazy i am going to follow it.



my PCB rn, its messy but will be very helpful later. 


now i dont know how to make PCB layout design of my own choice. LOL

dang it, i still couldn't figure how to make my own style PCB.

finally 


listen i was recording at late night i was planning to do 9 hrs but i was sleepy too actully very sleepy so there, and now this is morning and i dont know i i just slept, i dont remember anything at all how i sleep, so the thing is there might be still time in the recording u can deduct it.

its is from 6:40 to the end

### Recording Links

- https://lookout.hackclub.com/api/media/6b9c1379-9118-47a6-8ccf-576c08f5cb56/video.mp4

## Entry 21
- ID: 8951
- Author: Broccoli
- Created At: 2026-05-24T19:29:34Z

### Content

now i have completed the placement of all the components on the PCB the next phase will be routing the traces, but i dont even know the anything about how to do 4 layer PCB tho.





 i have added the inner layers and added the connection vias for GND and VDD33 but there is a problem that i cannot use the ESP32 S3 antenna for PN352 it need diiff coil to that will create a magnetic field, also as i have added the vias so it will be problematic to add antenna now, but still we cannot miss it. 



there is some un active time and some other things, i forget to pause it

### Recording Links

- https://lookout.hackclub.com/api/media/f2198c63-5a12-442c-ba36-c7585fd0b413/video.mp4

## Entry 22
- ID: 9333
- Author: Broccoli
- Created At: 2026-05-26T11:02:40Z

### Content

i locked in on routing, last day i had a problems with PN532 schematics, that i used wrong antenna. and the wrong footprints, then i used the correct antenna LOOP_ANTENNA 


now i am struggling with routing, it too hard there only 240 traces very less then my last keyboard, keyboard had 700 traces and it was easy cuz i had to much free space, but on this it is soo damn hard. 


### Recording Links

- https://lookout.hackclub.com/api/media/c4066519-7d85-403e-ab19-7871abba2c58/video.mp4

## Entry 23
- ID: 9402
- Author: Broccoli
- Created At: 2026-05-26T16:19:51Z

### Content

so it the end of this placement of components there are so messy and after antenna they are just shits, i am on my first component and i dont have any places to do routing in that area and with so many vias it dead, 




ans still 200+ traces left, duh duh duh 


i am going to remove all routes so far an vias, and do it again properly.

deleting my mehnat, lol 

deleted. 



damn damn damb

### Recording Links

- https://lookout.hackclub.com/api/media/b55dfb5d-e276-4572-9785-3fa9ba0226a8/video.mp4

## Entry 24
- ID: 9613
- Author: Broccoli
- Created At: 2026-05-27T09:09:19Z

### Content

now i did it gain in clean maner and it looks good rn, its also looka bulk tho, but for better RFID performance i did it it also gonna help me route easily. 

 adjusted the components and added the space, also i made a design rule area for antennas 


### Recording Links

- https://lookout.hackclub.com/api/media/f2e87ca3-2b5a-4308-8391-2bffd8b29ca9/video.mp4

## Entry 25
- ID: 9702
- Author: Broccoli
- Created At: 2026-05-27T17:32:17Z

### Content

now  i have to vias for GND and VDD33 and after that i have to do routing, i made a keep out zone and then add [ouring in the middle of antenna for PN332 , but i Cannot place vias there, isk why,


i i have to remove the design rule area because now it too hard to route PN532 that i placed init, i removed it for now, i will find a way later.

i deleted all the footprints again, cuz putting the PN532 in the center of antenna, make it hard for routing cuz i cant place vias there, or its performance will drop. 



this is the final, if anything happens again i will be done for, lol.  i didn't thought 4layer will be this hectic. 

so tuff



hell hell helll

and still 215 left, 


but it is going quite well this time, i hope it will be smooth like a butter for next 215 trace.

it is enough for today, 204 traces left i will di it tomorrow, 

once main MCU will bw done it wont be hard after that. 


### Recording Links

- https://lookout.hackclub.com/api/media/7d51b0ac-7e17-4787-a40e-76bf7b147b14/video.mp4

## Entry 26
- ID: 9880
- Author: Broccoli
- Created At: 2026-05-28T10:50:31Z

### Content

finally i have completed the all pins of ESP32 S3, also i have to make the traces 45% so they wont cuz any problem later, i hope that other components will be traced smoothly,. 

see how ESP32 S3 looks like rn:



they also said i shouldn't place vias on pads, i dk about it i will see them later.

 
this is getting hard by time, 

according to the KICAD only 74 traces left but they look too much, 


### Recording Links

- https://lookout.hackclub.com/api/media/6b261e60-2687-4d41-b853-2fbf4d320863/video.mp4

## Entry 27
- ID: 9914
- Author: Broccoli
- Created At: 2026-05-28T14:13:30Z

### Content

only 27 left.



the the only PN532 left after that we will run DRC, 

only one left, but i dont know where the hell it is.





time for 


ayyayayayyyya i am down to the only 


### Recording Links

- https://lookout.hackclub.com/api/media/f5025d2a-241f-44b3-afae-03b124917f70/video.mp4

## Entry 28
- ID: 10111
- Author: Broccoli
- Created At: 2026-05-29T11:13:36Z

### Content

i completed the PCB and all other things but there are still few error referring to antenna, i tried to solve but i failed, i have asked in fallout one guy said they are fine to ignore, the other said no they are critical. and u should not ignore them, but no one give the solution yet. until then i will be getting estimate for mt PCB from JLCPCB cuz i am going with PCBA. 

idk why is but PCBA not working for me 


now gonna try on PCB way

PCBway is sooo confusing, so i am waiting till the JLCPCB works until then i will work on CAD, i have planed to make it similar to wokytakie, 

this is just 1% how it looks 


gonna genrate a better one with grok, so have img as a reference 

now gonna start CAD, 

and this CAD defiantly gonna be hard, cuz i only know basic designs, but this time is want ti more professional and attractive.

dman i have to complete the CAD in next 2 days or i will be cooked, cuz fusion free tral will be ending in 2 days, 


ooo shit is forgot to add mouting hole before exporting.step now i ahve to do it, 

### Recording Links

- https://lookout.hackclub.com/api/media/a19a1b49-a06a-4c5d-8645-d8dcc5ef4d7c/video.mp4

## Entry 29
- ID: 10118
- Author: Broccoli
- Created At: 2026-05-29T12:07:15Z

### Content

added the mounting holes 


now i am fully ready to move to CAD

now i am getting soo frustrated, why they make these software soo complex. and make them hard to locate option in them , i am sooo frustrated 😤 

fusion is shit, i am going with freecad

### Recording Links

- https://lookout.hackclub.com/api/media/918795d6-3342-464d-a583-140405690019/video.mp4

## Entry 30
- ID: 10233
- Author: Broccoli
- Created At: 2026-05-29T19:43:39Z

### Content


gonna use this display, now i found the display i will download and make the CAD according to this.

i have started building CAD in fusion 360 i hope i complete it till tomorrow or i will be done for,

so far i have made case and its cap 



so i have completed the main design now i need to add hoole for buttons and and leds



cad is almost done now, but i think the upper cap that i created is not a single body, i think they are 2 bodies, now i have to figure out. and make them one body

damn this wasn't hard at all.  it just take me 1 min to combine two bodies into one

damn looks cool



i think its done. i know it looks boring but i will add stickers on it. 

now i done with cad now just i need to export the files, like .step and full project file. 

idk why but fusion 360 is opening automatically again and again, idk why. 
and shouting down isk why. 
i think i should sleep now, i am still awake and its midnight rn, 

oky soo i am sleeping now gonna do else things tomorrow, and they day after tomorrow i will submit this, yayyaya

### Recording Links

- https://lookout.hackclub.com/api/media/52deb5fc-9c5d-44bb-984b-ee6304005fc0/video.mp4

## Entry 31
- ID: 10324
- Author: Broccoli
- Created At: 2026-05-30T05:33:41Z

### Content

last day i completed the CAD, and exported the main folder, but failed to export step files due to crash of Fusion 360, now i am gonna export the .step files and organize the main  folder, with CAD, PCB and assets, and then we will move to ZINE and firmware, my github desktop is not pushing the commits to origin idk why, maybe file are too long, 



exported my step files. now time to take some shots for the zine

the firmware structure is done, it not full frimware and i ma not gonna build it until i build irl,

### Recording Links

- https://lookout.hackclub.com/api/media/098ab471-371f-4636-b428-76d54d0d06d8/video.mp4

## Entry 32
- ID: 10637
- Author: Broccoli
- Created At: 2026-05-31T11:15:15Z

### Content

i was just reviewing the my PCB with mu online fren and he told me that u dont have any SD card for storing attacks and all there kind of files, and we dont have speaker or microphone for lora communication. now i need to add them to make it more batter, this will be a very good upgrade. 



added the SD card, and i am skipping the audios cuz i dont have that much pins for all that, i will add that in V2 for V1 i will be using chat options with typing touch displays. 

now i have to solve the antenna error somehow. 

now i have reviewed the all schematic again to make sure all things are alright or not. now gonna add the footprints and give it a right location

idk why the footprint is not correct 



SD card added 


now it looks much better 


now the only those 4 errors left, i think it will gonna took me wile to see what the solution



damn i am not able to find the solutions for the error

### Recording Links

- https://lookout.hackclub.com/api/media/79115fe6-75df-4ebd-8f6b-195135959d6e/video.mp4

## Entry 33
- ID: 10939
- Author: Broccoli
- Created At: 2026-06-01T17:25:22Z

### Content

today i started making my ZINE, i used the BG from and diff site i hope it will be acceptable . 

this is how it looks rn idk what colour of text will be best here, i tried few but cant find the good match 

Flipper Black.png

### Recording Links

- https://lookout.hackclub.com/api/media/63d8c5c1-b90c-46d8-93e7-a3886b0d4ac1/video.mp4

## Entry 34
- ID: 11156
- Author: Broccoli
- Created At: 2026-06-02T16:10:56Z

### Content

dang it, i started making my ZINE again from scratch but idk why it didn't get recorded idk, i remember i started it and when i try to pause it it wasn't started, they were like 1.5 hrs, anyway i dont have to worry about hrs i alredy have 180hrs yayayayayya 😉, 

here is new zine, 


i used the same casing added shaded on antenna, added text and text looks more cool then last time, 

i messed up again shit, 

so now i have completed it now lets share it on slack and see if guys  likes it or not, 

here is the final look 
A5 - 1 (1).png

git some idea for zine now gonna add them  

### Recording Links

- https://lookout.hackclub.com/api/media/aebd8a1a-2db1-4ce3-b732-8e0f2852300e/video.mp4

## Entry 35
- ID: 11182
- Author: Broccoli
- Created At: 2026-06-02T17:44:03Z

### Content

made some changes in the zine and it looks more better now, add the names for antennas. 
Untitled (4).png

it looks to much better now,   

### Recording Links

- https://lookout.hackclub.com/api/media/99e2c42b-2c89-458c-9787-ea2507c73658/video.mp4
- https://lookout.hackclub.com/api/media/4364c9a1-38d0-40b0-ac5a-d411d1ca8818/video.mp4

## Entry 36
- ID: 11825
- Author: Broccoli
- Created At: 2026-06-05T12:26:19Z

### Content

TODAY I STARTED MAKING MY REPO BEAUTIFUL, RN MAKING MY PROFESSIONAL README, GETTING INSPRATION FROM OTHER TO MAKE IT MORE PROFESSIONAL.

ADDED THE BADGES 



AFTER THIS I WILL BE SOURCING THE PARTS AND COMPONENTS FOR IT, 

added the imgs 



feature so  looks good and charming yayayayyayay


### Recording Links

- https://lookout.hackclub.com/api/media/fc3eef3d-4257-4d3f-83f4-52045e51f4d1/video.mp4

## Entry 37
- ID: 11890
- Author: Broccoli
- Created At: 2026-06-05T17:44:01Z

### Content


completed my readme now i just need to add few things init, like ZINE preview and BOM, then it will be fully done. 

yayayayayayayyayayayaay

now that readme is complete now goona make a BOM, this definitely gonna be hard, also posting on slack to have a senity check done., 

now gonna lock in on BOM, 

i tried using lcsc auto bom finder but it not working because i did mess in bom. 

almost all done few  left

### Recording Links

- https://lookout.hackclub.com/api/media/7ebbdab6-80d5-4394-807f-97450611315d/video.mp4

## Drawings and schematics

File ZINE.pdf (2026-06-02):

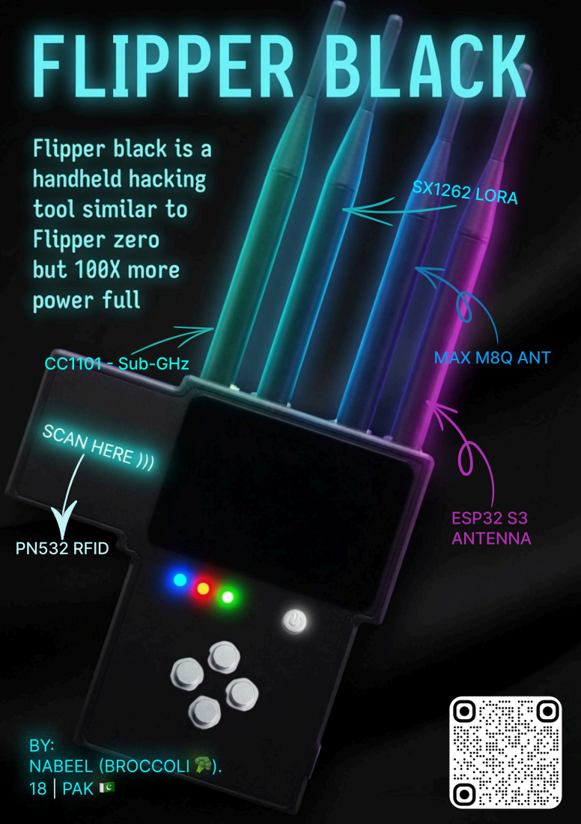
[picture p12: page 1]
SX1262 LORA; CC1101 - Sub-GHz; MAX M8Q ANT; PN532 RFID; ESP32 S3 ANTENNA

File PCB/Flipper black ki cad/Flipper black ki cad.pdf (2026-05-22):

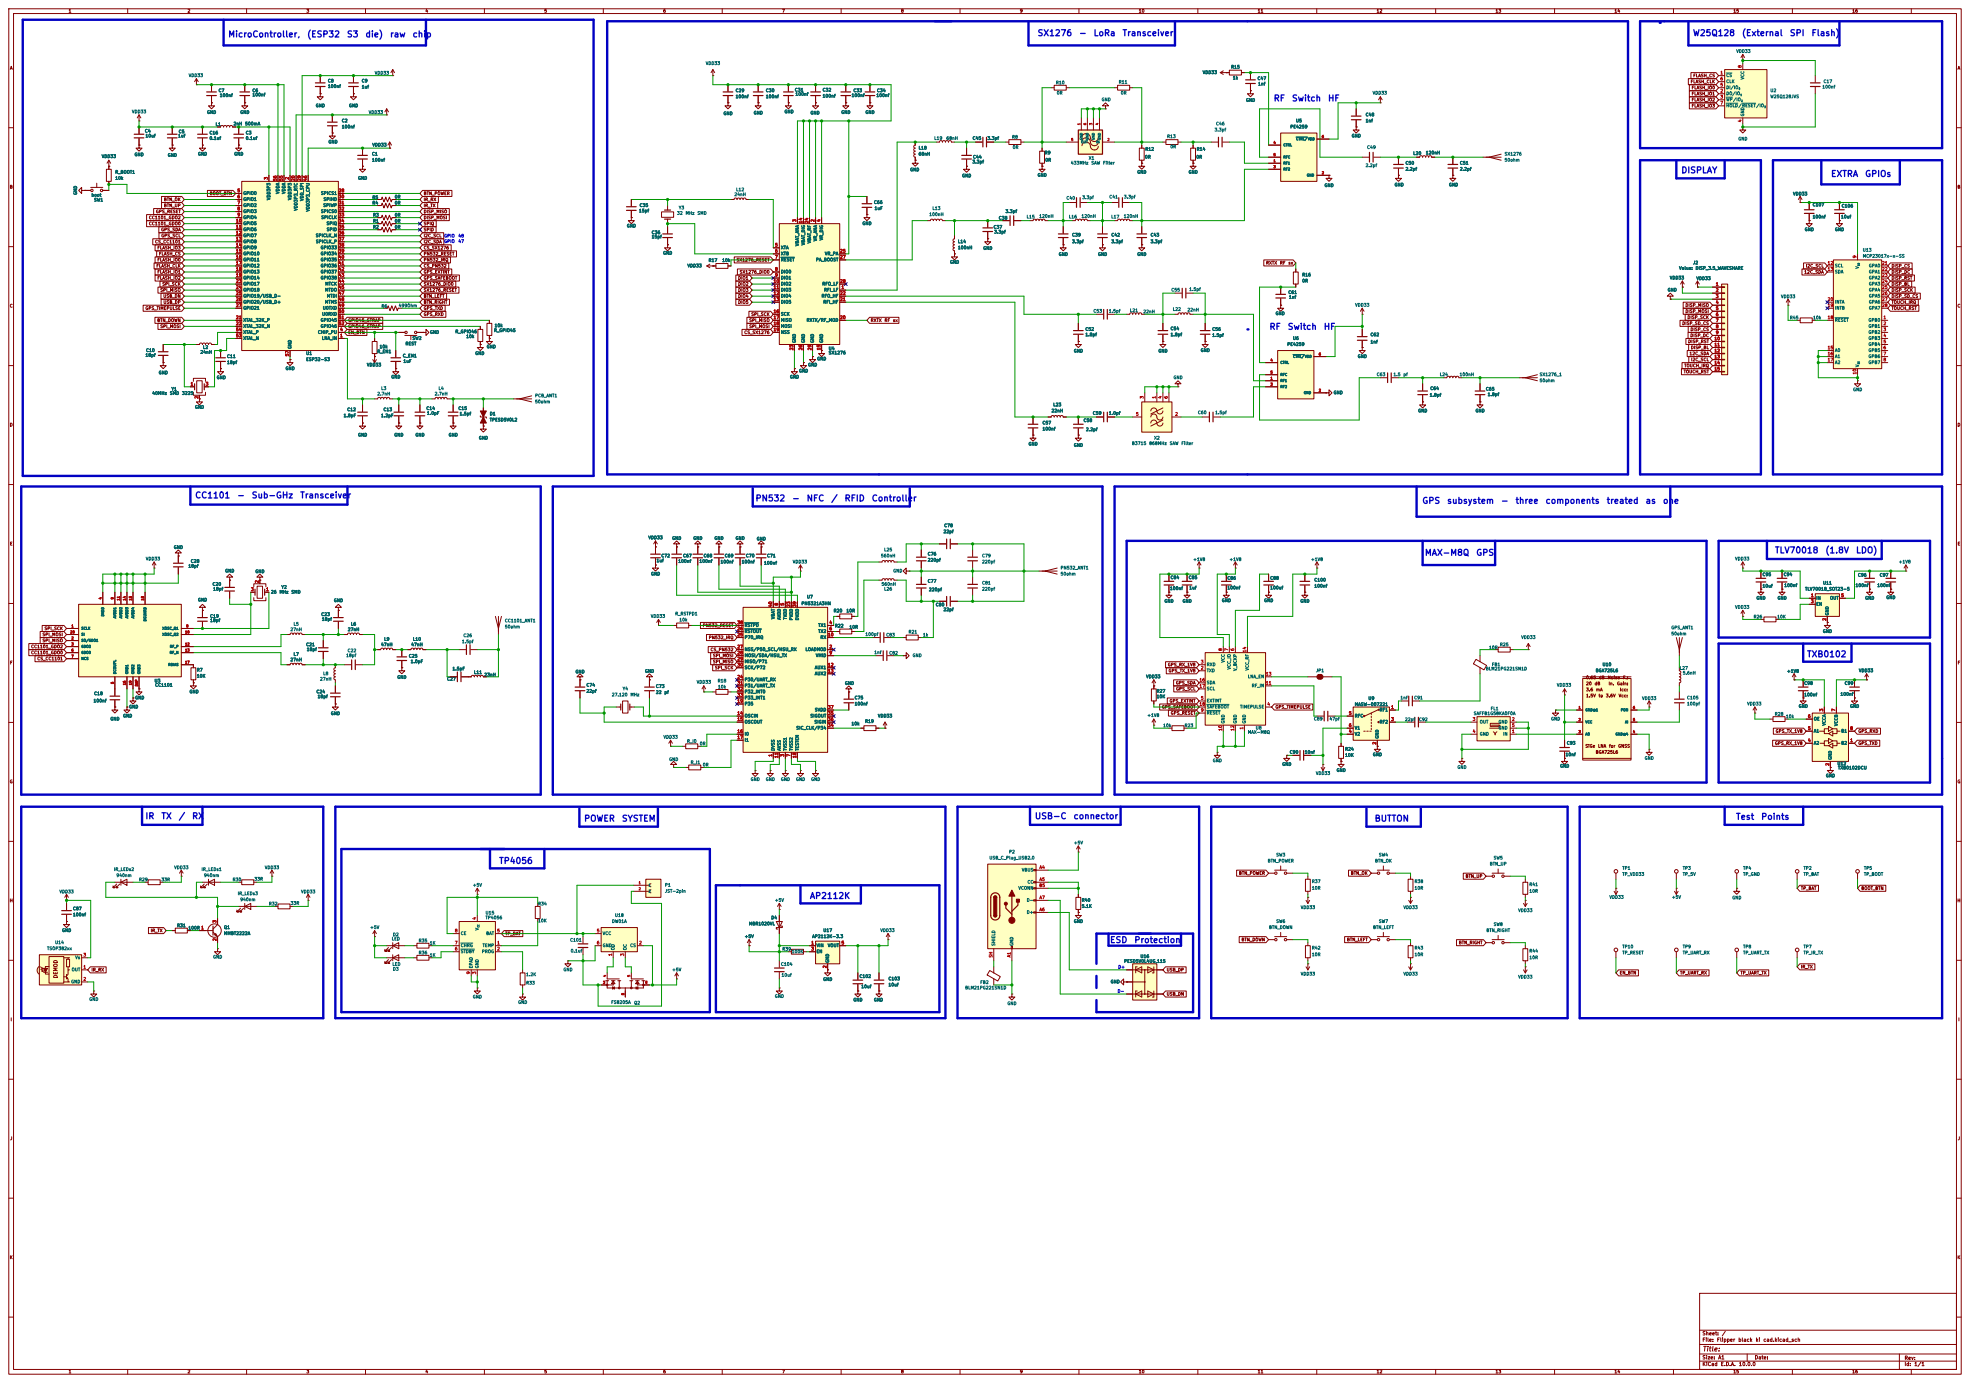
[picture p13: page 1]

MicroController, (ESP32 S3 die) raw chip

RXTX RF sx SPID
GPIO 47

GPS subsystem - three components treated as one

SiGe LNA for GNSS

Sheet: /
File: Flipper black ki cad.kicad_sch
Title:

Size: A1 | Rev:
KiCad E.D.A. 10.0.0 | Id: 1/1

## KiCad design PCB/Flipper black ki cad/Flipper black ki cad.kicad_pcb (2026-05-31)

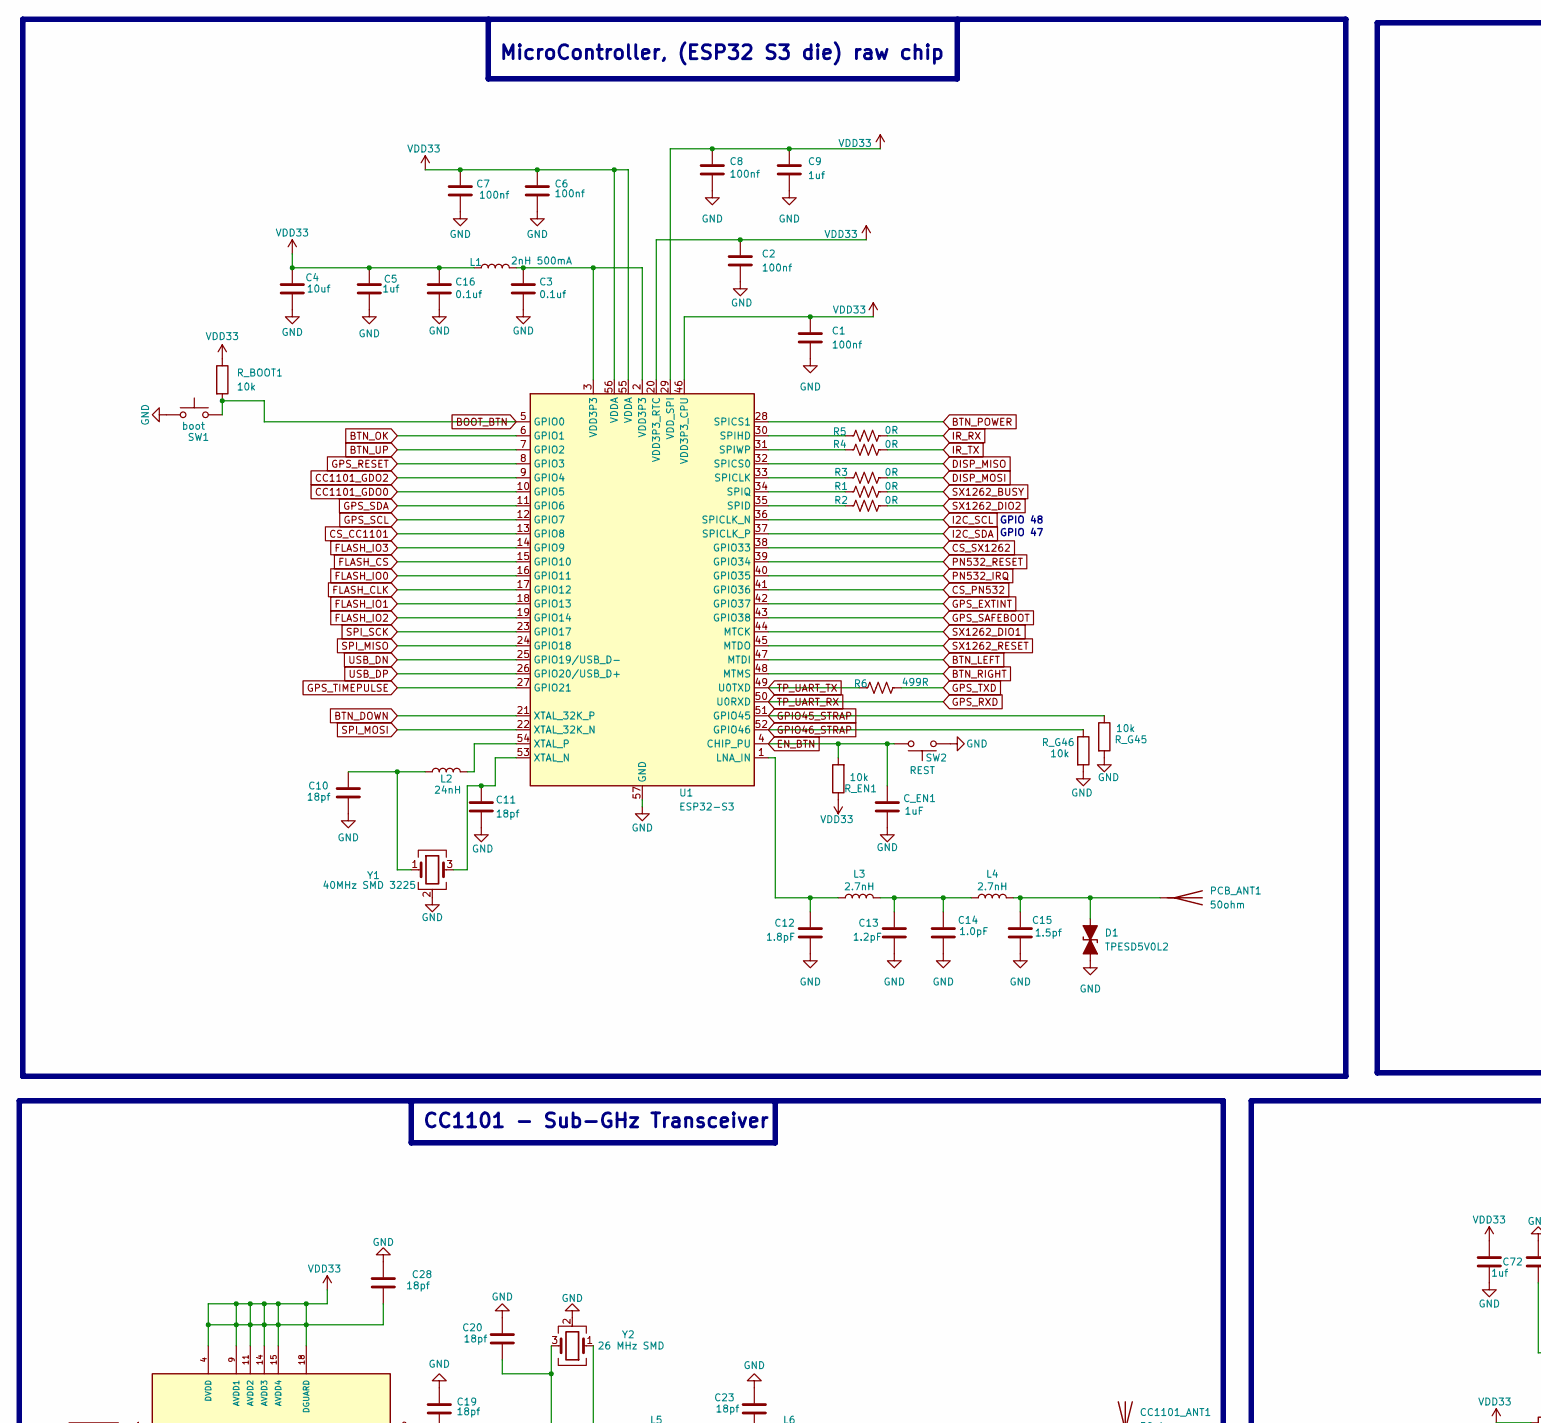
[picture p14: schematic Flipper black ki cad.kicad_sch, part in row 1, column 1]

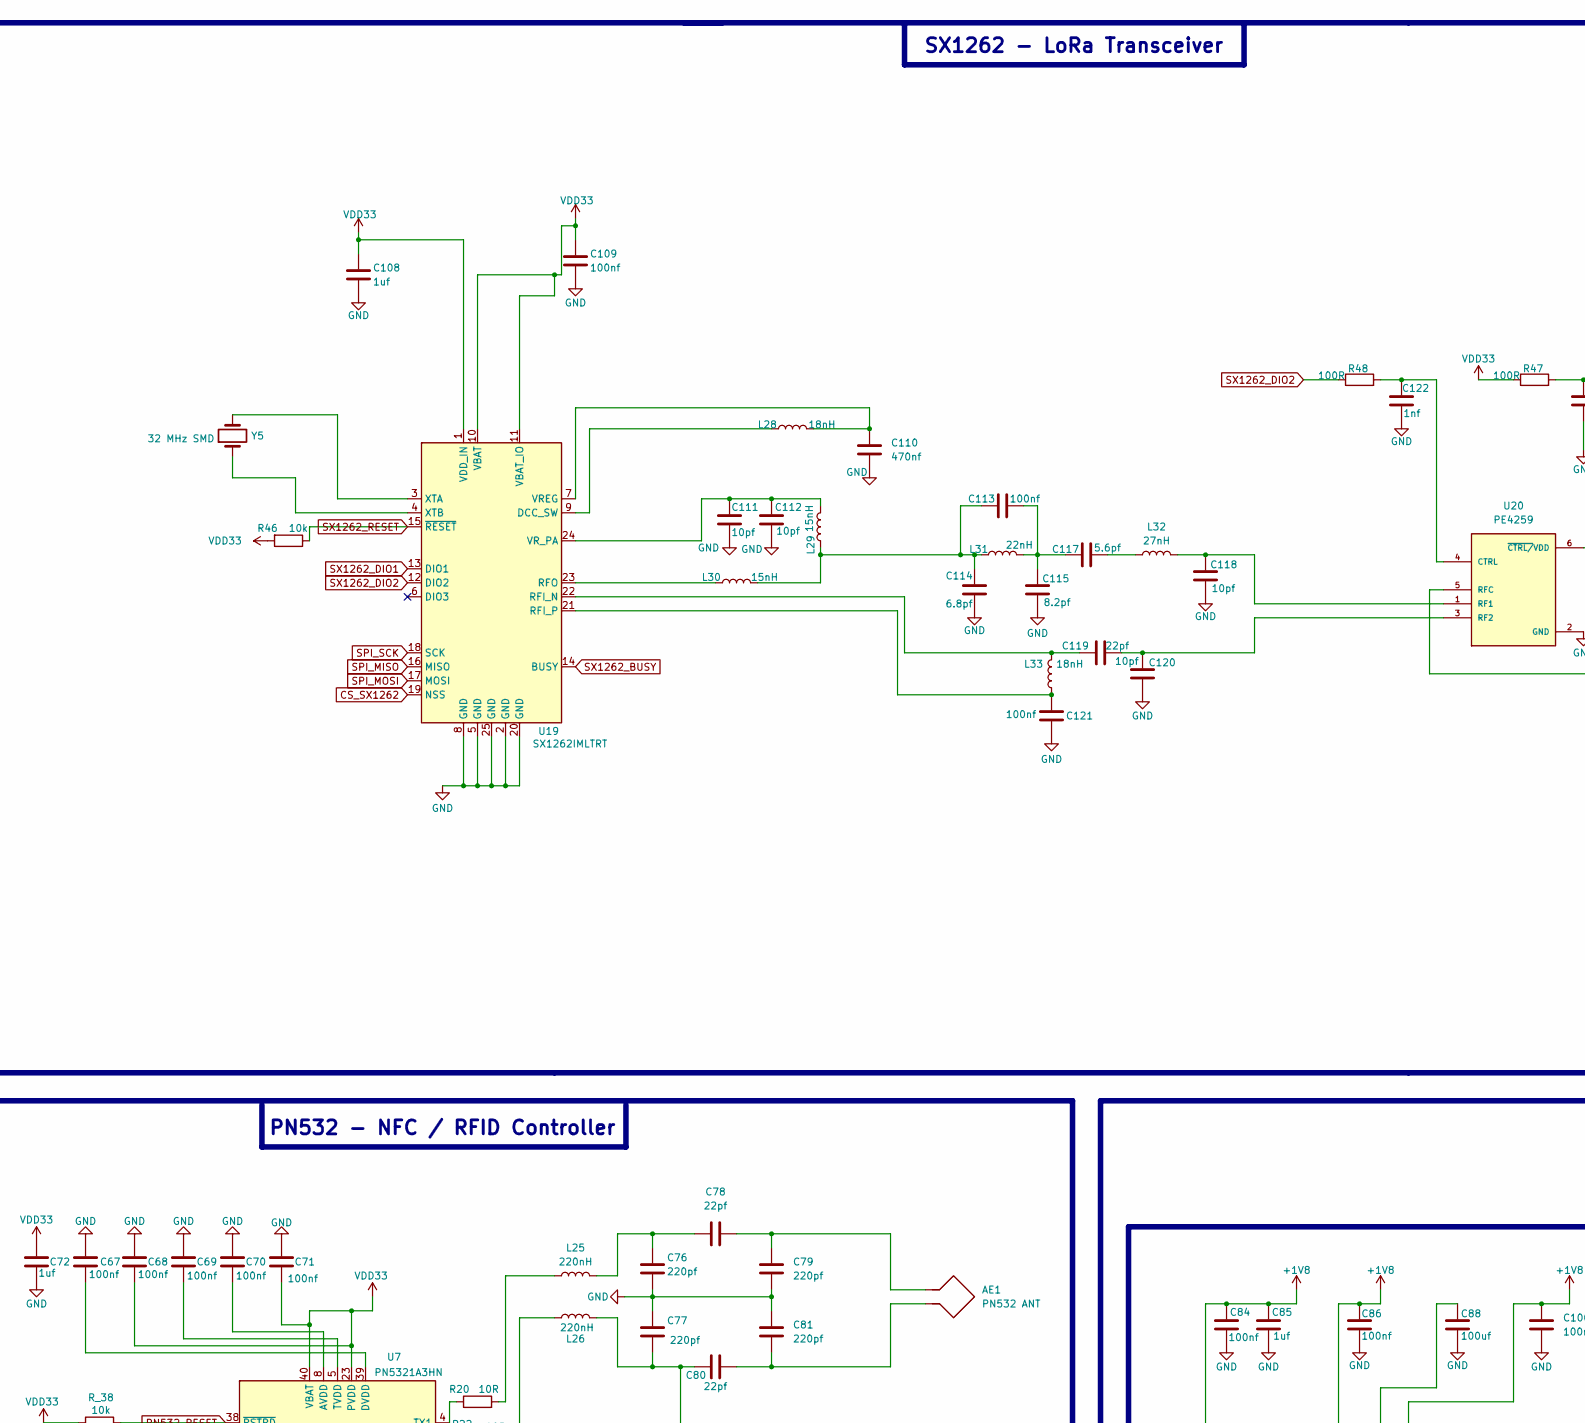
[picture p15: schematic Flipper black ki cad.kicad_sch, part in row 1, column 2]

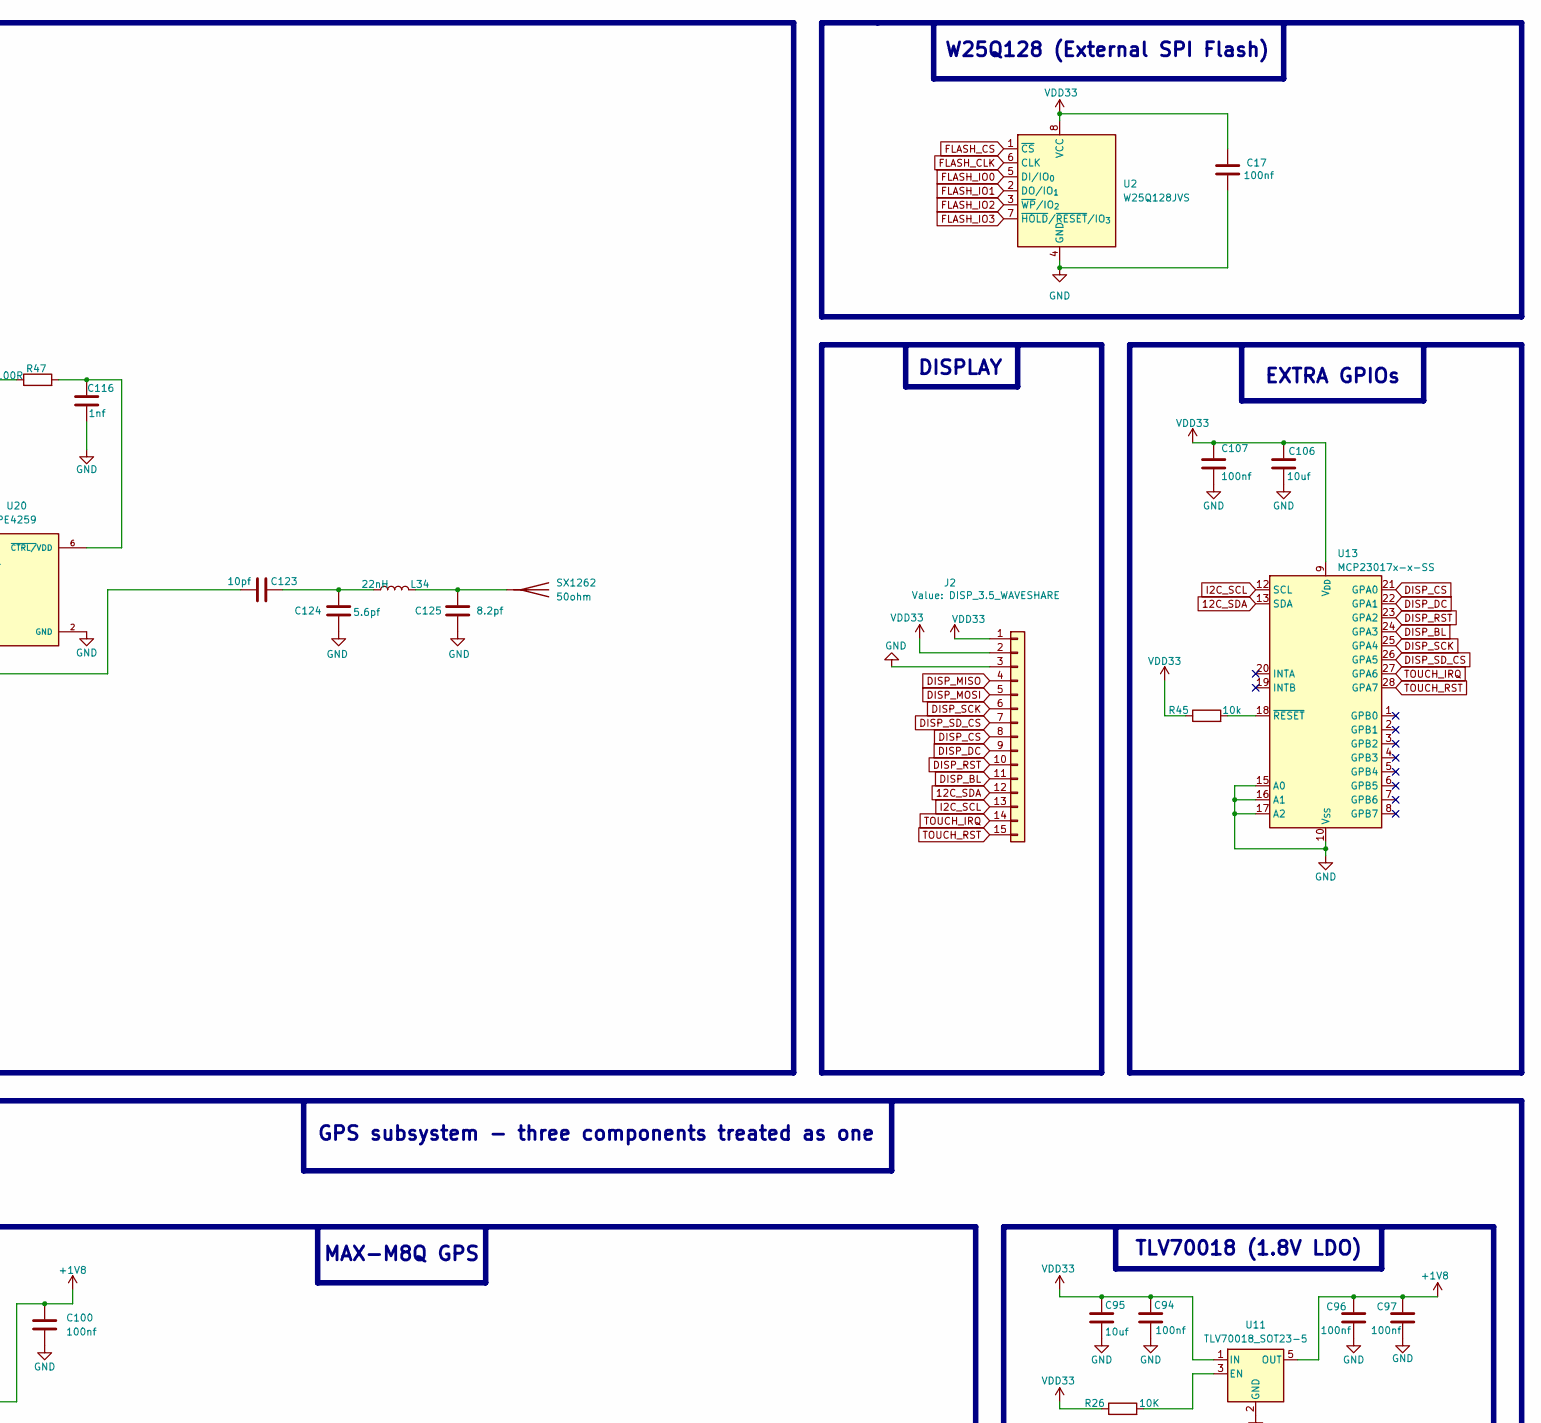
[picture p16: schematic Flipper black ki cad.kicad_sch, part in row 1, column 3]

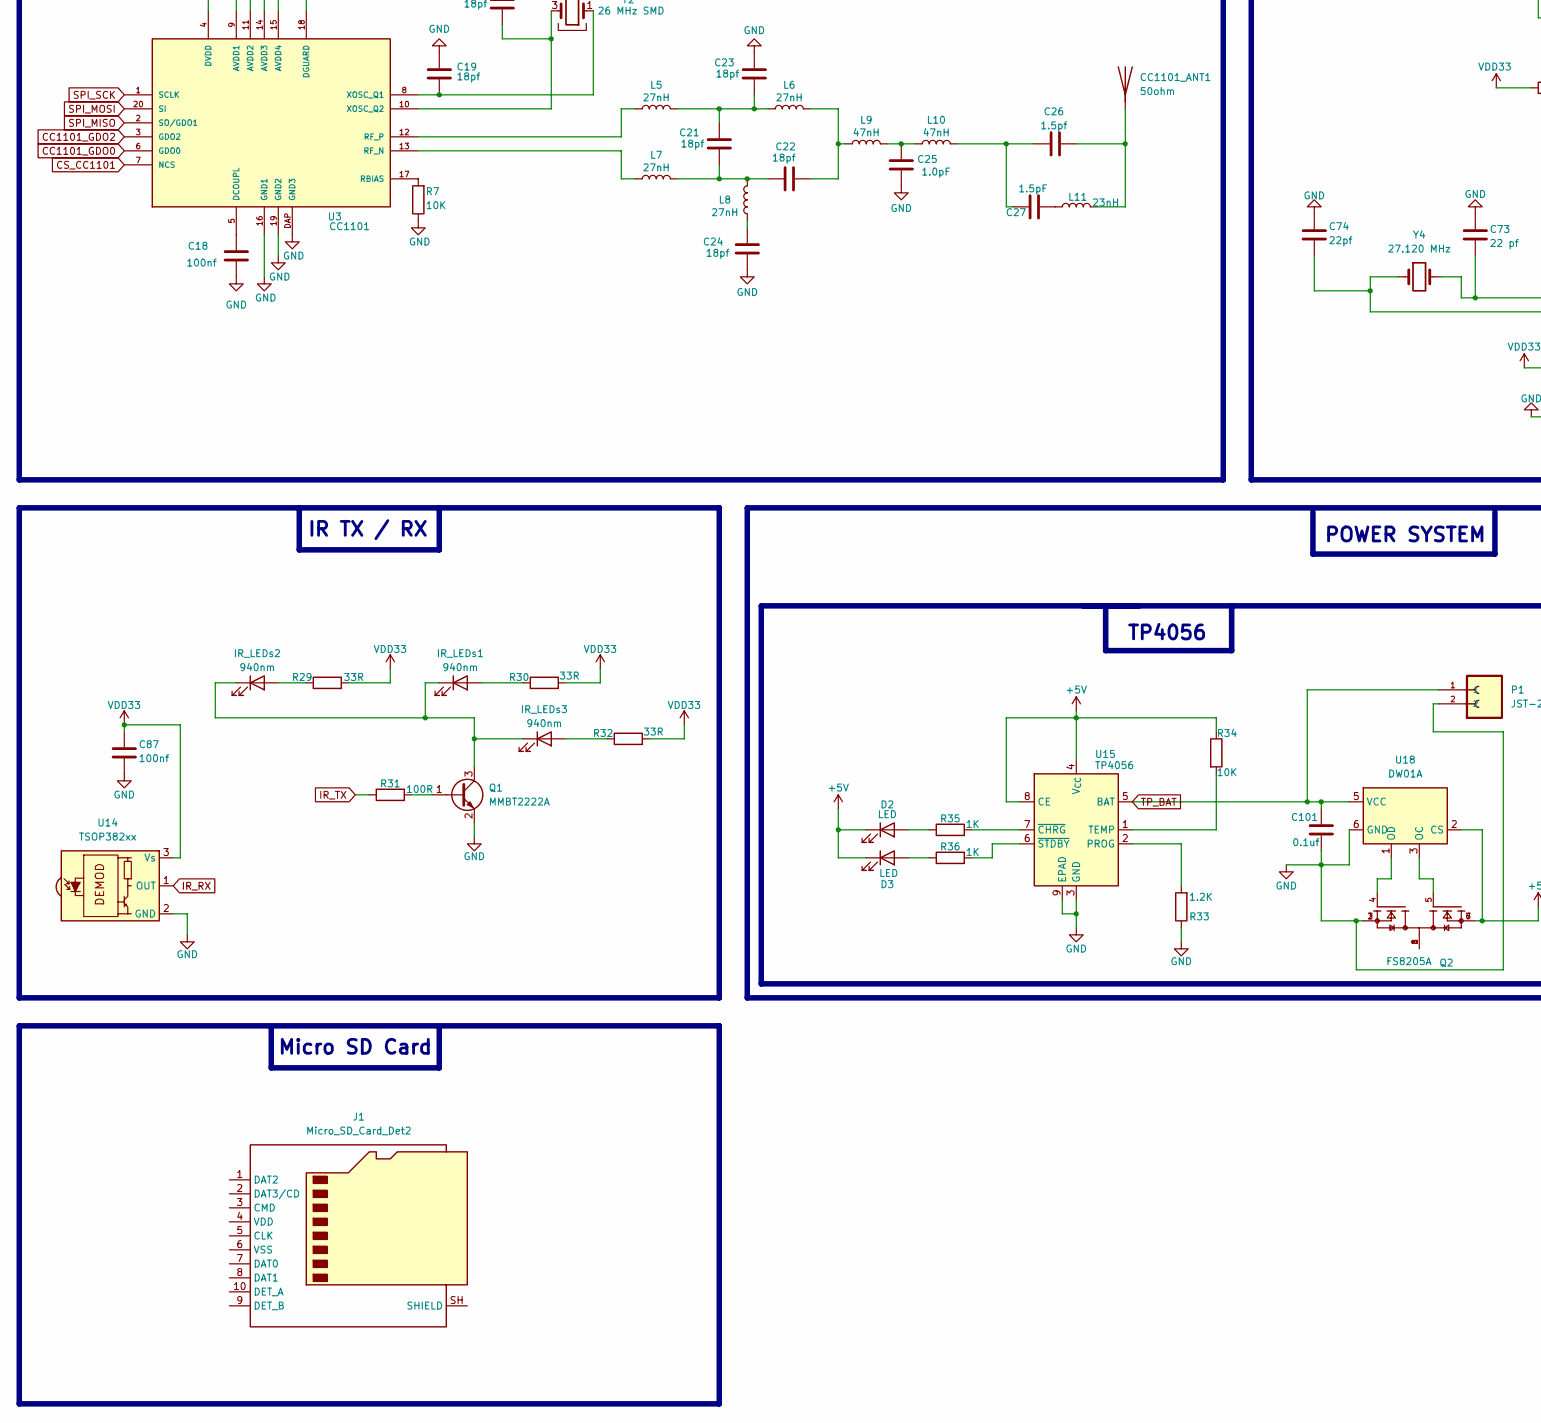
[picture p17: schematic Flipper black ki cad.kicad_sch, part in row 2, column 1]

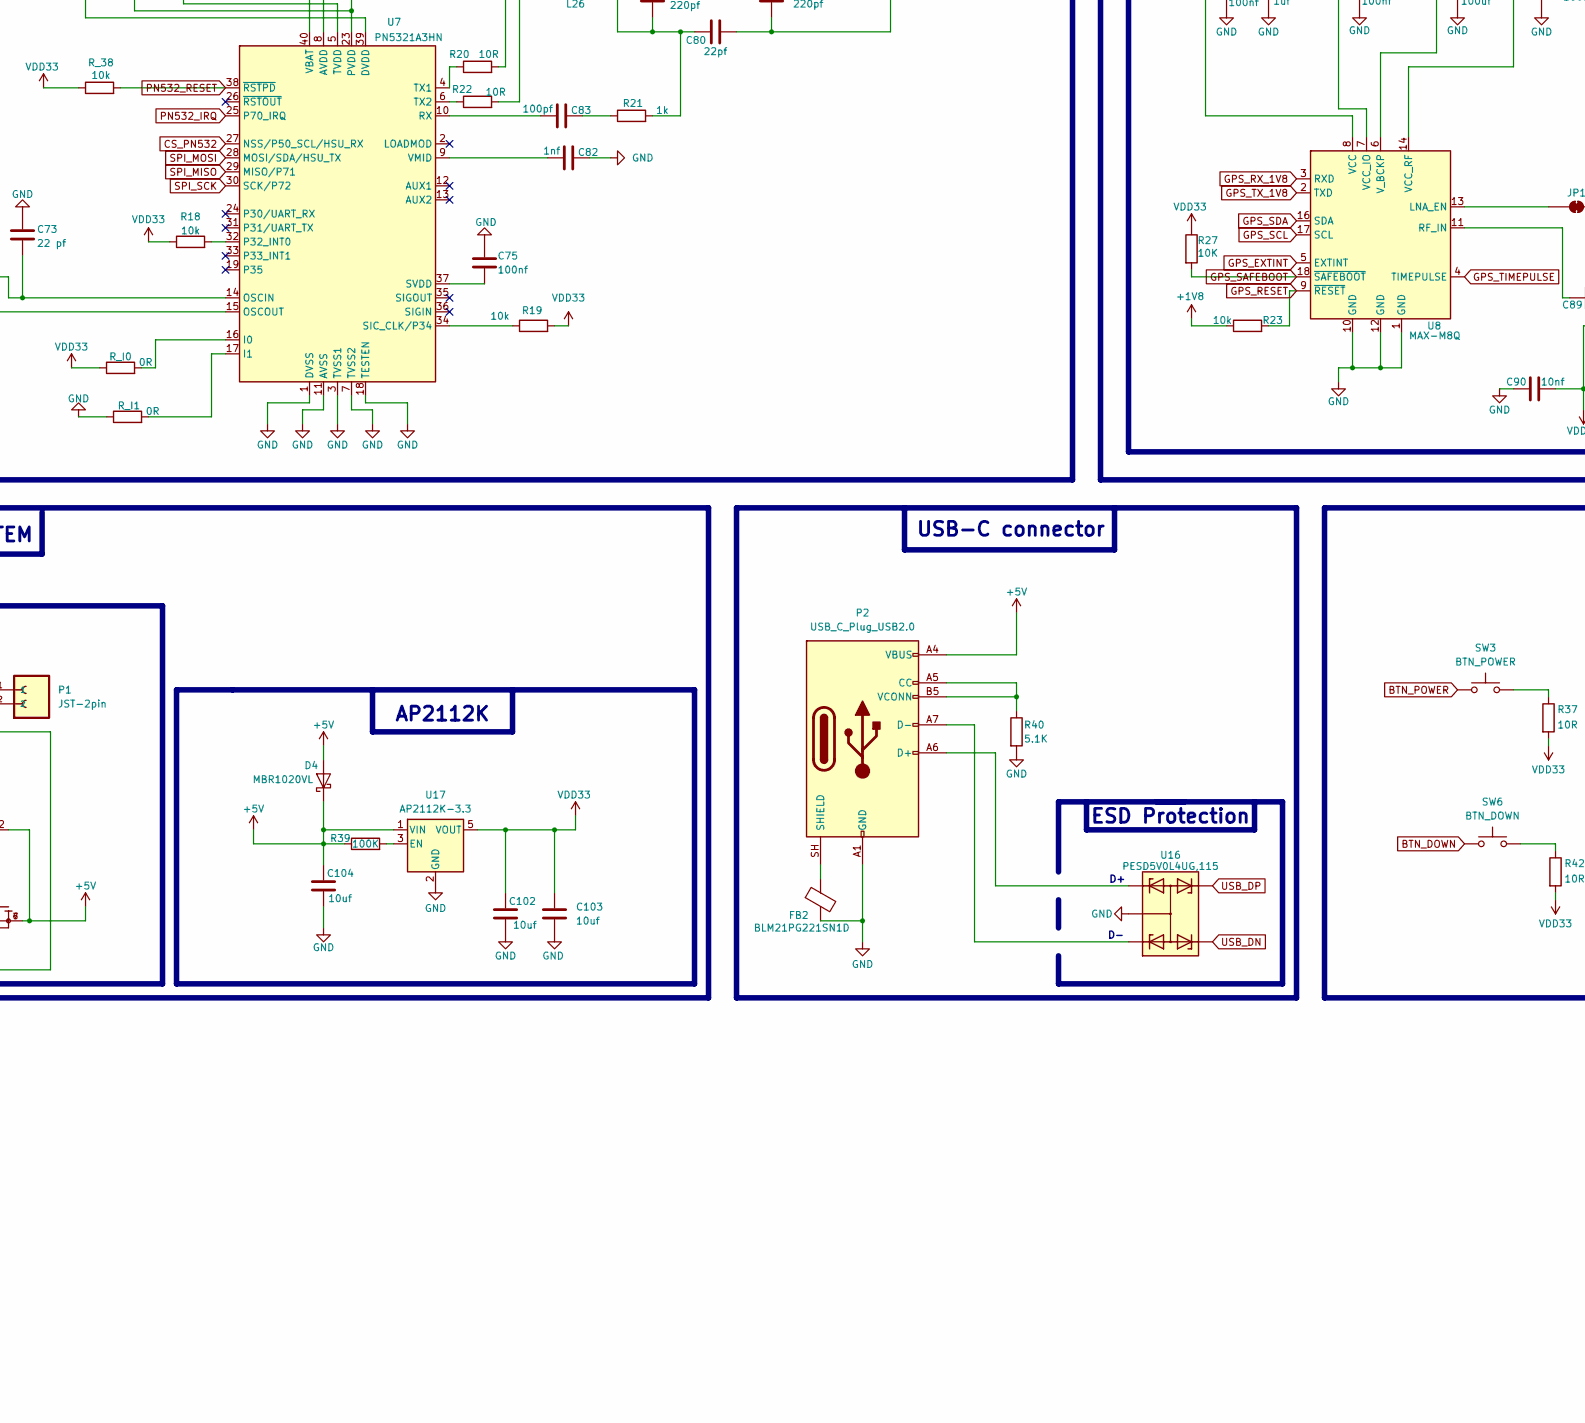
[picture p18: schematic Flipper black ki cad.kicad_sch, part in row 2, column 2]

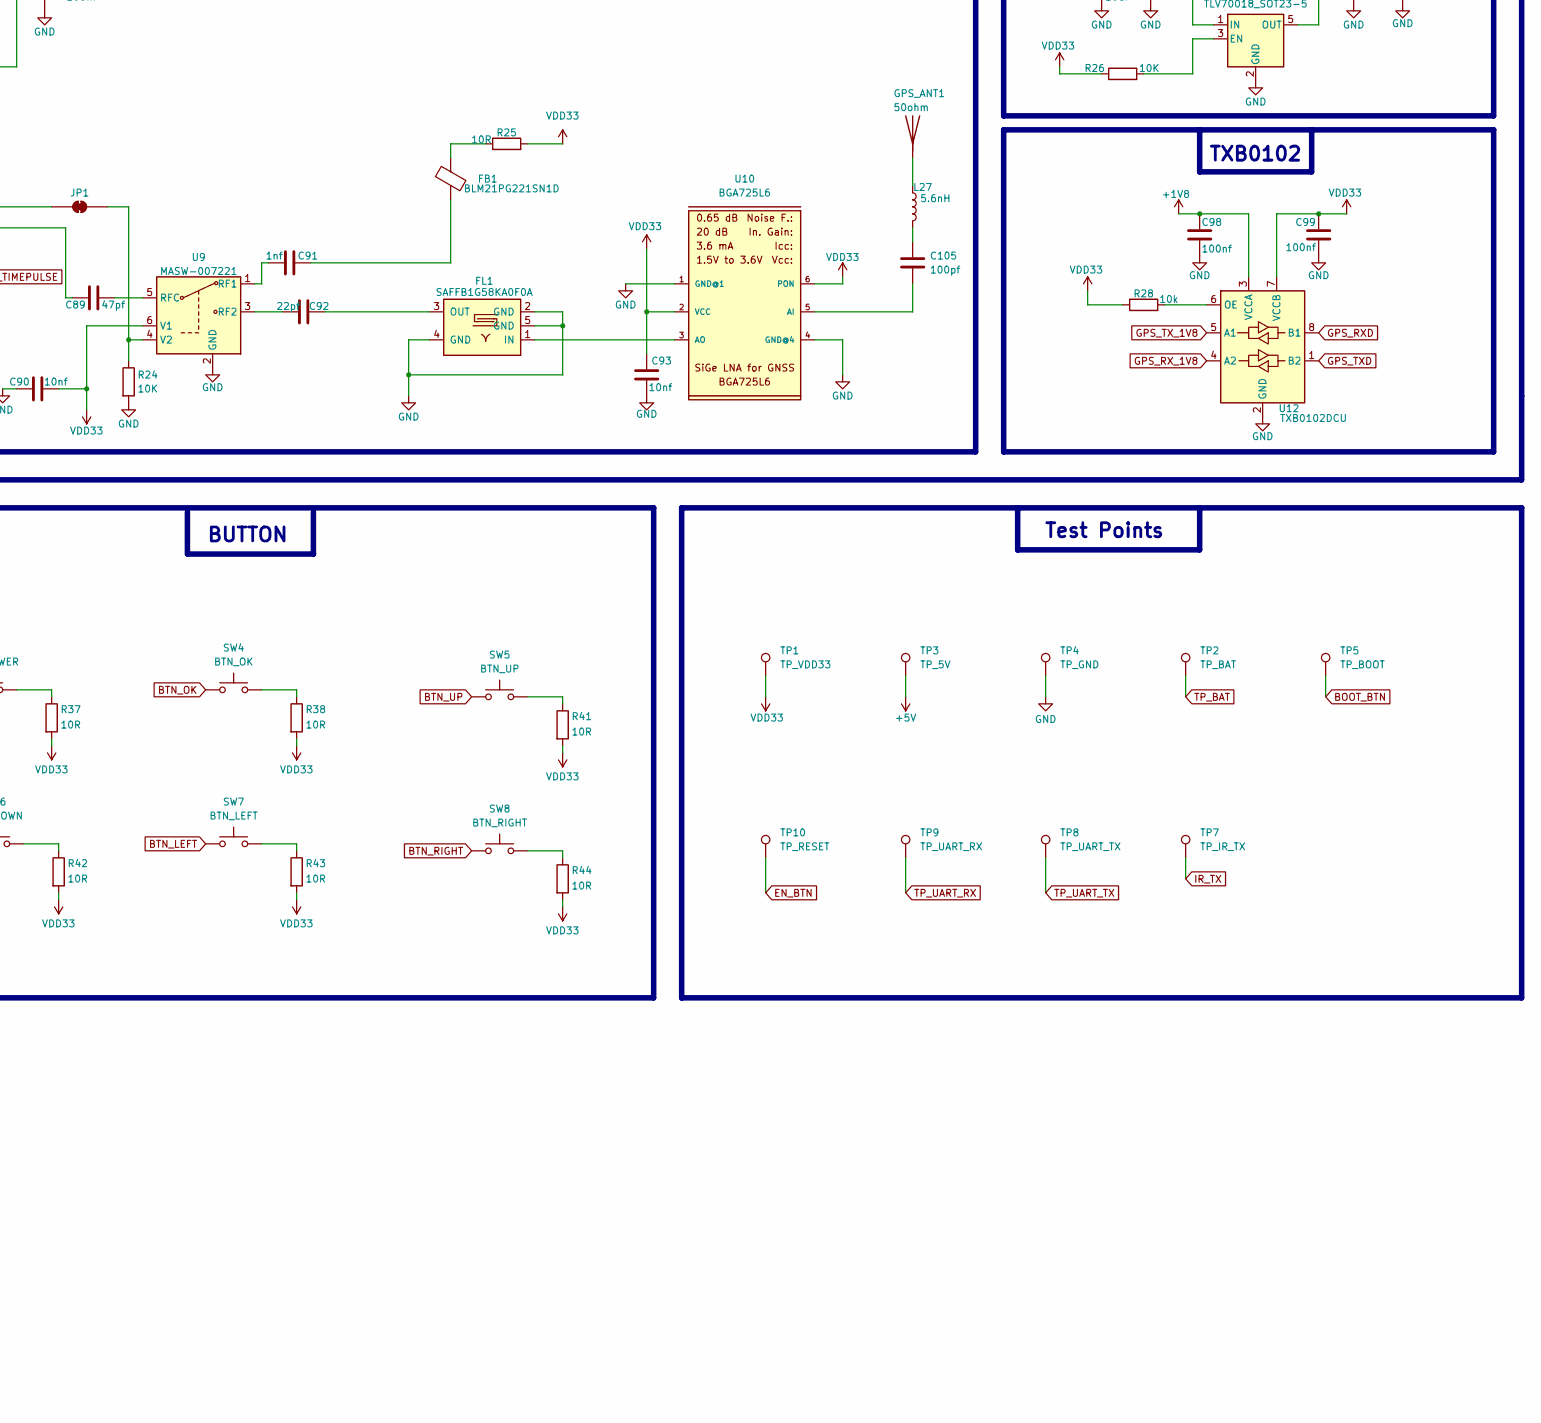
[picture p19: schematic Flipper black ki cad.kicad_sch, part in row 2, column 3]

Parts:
AE1: PN532 ANT; NFC_45x45_N4_NXP_PN5180
C1, C2, C6, C7, C8, C17, C18, C67, C68, C69, C70, C71, C75, C84, C86, C87, C94, C96, C97, C98, C99, C100, C107, C109, C113, C121: 100nf; C_0603_1608Metric_Pad1.08x0.95mm_HandSolder
C3, C16, C101: 0.1uf; C_0603_1608Metric_Pad1.08x0.95mm_HandSolder
C4, C95, C102, C103, C104, C106: 10uf; C_0603_1608Metric_Pad1.08x0.95mm_HandSolder
C5, C9, C72, C85, C108: 1uf; C_0603_1608Metric_Pad1.08x0.95mm_HandSolder
C10, C11, C19, C20, C21, C22, C23, C24, C28: 18pf; C_0603_1608Metric_Pad1.08x0.95mm_HandSolder
C12: 1.8pF; C_0603_1608Metric_Pad1.08x0.95mm_HandSolder
C13: 1.2pF; C_0603_1608Metric_Pad1.08x0.95mm_HandSolder
C14, C25: 1.0pF; C_0603_1608Metric_Pad1.08x0.95mm_HandSolder
C15, C26: 1.5pf; C_0603_1608Metric_Pad1.08x0.95mm_HandSolder
C27: 1.5pF; C_0603_1608Metric_Pad1.08x0.95mm_HandSolder
C73: 22 pf; C_0603_1608Metric_Pad1.08x0.95mm_HandSolder
C74, C78, C80, C92, C119: 22pf; C_0603_1608Metric_Pad1.08x0.95mm_HandSolder
C76, C77, C79, C81: 220pf; C_0603_1608Metric_Pad1.08x0.95mm_HandSolder
C82, C91, C116, C122: 1nf; C_0603_1608Metric_Pad1.08x0.95mm_HandSolder
C83, C105: 100pf; C_0603_1608Metric_Pad1.08x0.95mm_HandSolder
C88: 100uf; C_0603_1608Metric_Pad1.08x0.95mm_HandSolder
C89: 47pf; C_0603_1608Metric_Pad1.08x0.95mm_HandSolder
C90, C93: 10nf; C_0603_1608Metric_Pad1.08x0.95mm_HandSolder
C110: 470nf; C_0603_1608Metric_Pad1.08x0.95mm_HandSolder
C111, C112, C118, C120, C123: 10pf; C_0603_1608Metric_Pad1.08x0.95mm_HandSolder
C114: 6.8pf; C_0603_1608Metric_Pad1.08x0.95mm_HandSolder
C115, C125: 8.2pf; C_0603_1608Metric_Pad1.08x0.95mm_HandSolder
C117, C124: 5.6pf; C_0603_1608Metric_Pad1.08x0.95mm_HandSolder
CC1101_ANT1: 50ohm; U.FL_Hirose_U.FL-R-SMT-1_Vertical
C_EN1: 1uF; C_0603_1608Metric_Pad1.08x0.95mm_HandSolder
D1: TPESD5V0L2; D_SOD-323_HandSoldering
D2, D3: LED; LED_0603_1608Metric_Pad1.05x0.95mm_HandSolder
D4: MBR1020VL; D_SOD-123F
FB1, FB2: BLM21PG221SN1D; L_0603_1608Metric_Pad1.05x0.95mm_HandSolder
FL1: SAFFB1G58KA0F0A; Filter_1109-5_1.1x0.9mm
GPS_ANT1: 50ohm; U.FL_Hirose_U.FL-R-SMT-1_Vertical
IR_LEDs1, IR_LEDs2, IR_LEDs3: 940nm; LED_1206_3216Metric
J1: Micro_SD_Card_Det2
J2: Value: DISP_3.5_WAVESHARE; Amphenol_F32Q-1A7x1-11015_1x15-1MP_P0.5mm_Horizontal
JP1: SolderJumper_2_Bridged; SolderJumper-2_P1.3mm_Bridged2Bar_Pad1.0x1.5mm
L1: 2nH 500mA; L_0603_1608Metric_Pad1.05x0.95mm_HandSolder
L2: 24nH; L_0603_1608Metric_Pad1.05x0.95mm_HandSolder
L3, L4: 2.7nH; L_0603_1608Metric_Pad1.05x0.95mm_HandSolder
L5, L6, L7, L8, L32: 27nH; L_0603_1608Metric_Pad1.05x0.95mm_HandSolder
L9, L10: 47nH; L_0603_1608Metric_Pad1.05x0.95mm_HandSolder
L11: 23nH; L_0603_1608Metric_Pad1.05x0.95mm_HandSolder
L25, L26: 220nH; L_0603_1608Metric_Pad1.05x0.95mm_HandSolder
L27: 5.6nH; L_0603_1608Metric_Pad1.05x0.95mm_HandSolder
L28, L33: 18nH; L_0603_1608Metric_Pad1.05x0.95mm_HandSolder
L29, L30: 15nH; L_0603_1608Metric_Pad1.05x0.95mm_HandSolder
L31, L34: 22nH; L_0603_1608Metric_Pad1.05x0.95mm_HandSolder
P1: JST-2pin; JST_PH_S2B-PH-SM4-TB_1x02-1MP_P2.00mm_Horizontal
P2: USB_C_Plug_USB2.0; USB_C_Receptacle_GCT_USB4105-xx-A_16P_TopMnt_Horizontal
PCB_ANT1: 50ohm; U.FL_Hirose_U.FL-R-SMT-1_Vertical
Q1: MMBT2222A; SOT-23
Q2: FS8205A; SOP65P640X120-8N; PARTREV 1.7
R1, R2, R3, R4, R5: 0R; R_0402_1005Metric
R6: 499R; R_0402_1005Metric
R7, R24, R26, R27, R34: 10K; R_0402_1005Metric
R18, R19, R23, R28, R45, R46: 10k; R_0402_1005Metric
R20, R22, R25, R37, R38, R41, R42, R43, R44: 10R; R_0402_1005Metric
R21: 1k; R_0402_1005Metric
R29, R30, R32: 33R; R_0402_1005Metric
R31, R47, R48: 100R; R_0402_1005Metric
R33: 1.2K; R_0402_1005Metric
R35, R36: 1K; R_0402_1005Metric
R39: 100K; R_0402_1005Metric
R40: 5.1K; R_0402_1005Metric
R_38: 10k; R_0402_1005Metric
R_BOOT1: 10k; R_0402_1005Metric
R_EN1: 10k; R_0402_1005Metric
R_G45, R_G46: 10k; R_0402_1005Metric
R_I0, R_I1: 0R; R_0402_1005Metric
SW1: boot; SW_SPST_B3U-1000P
SW2: REST; SW_SPST_B3U-1000P
SW3: BTN_POWER; SW_PTS645SH43SMTR92LFS
SW4: BTN_OK; SW_PTS645SH43SMTR92LFS
SW5: BTN_UP; SW_PTS645SH43SMTR92LFS
SW6: BTN_DOWN; SW_PTS645SH43SMTR92LFS
SW7: BTN_LEFT; SW_PTS645SH43SMTR92LFS
SW8: BTN_RIGHT; SW_PTS645SH43SMTR92LFS
SX1262: 50ohm; U.FL_Hirose_U.FL-R-SMT-1_Vertical
TP1: TP_VDD33; TestPoint_Pad_D1.0mm
TP2: TP_BAT; TestPoint_Pad_D1.0mm
TP3: TP_5V; TestPoint_Pad_D1.0mm
TP4: TP_GND; TestPoint_Pad_D1.0mm
TP5: TP_BOOT; TestPoint_Pad_D1.0mm
TP7: TP_IR_TX; TestPoint_Pad_D1.0mm
TP8: TP_UART_TX; TestPoint_Pad_D1.0mm
TP9: TP_UART_RX; TestPoint_Pad_D1.0mm
TP10: TP_RESET; TestPoint_Pad_D1.0mm
U1: ESP32-S3; QFN-56-1EP_7x7mm_P0.4mm_EP4x4mm
U2: W25Q128JVS; SOIC-8_5.3x5.3mm_P1.27mm
U3: CC1101; QLP20
U7: PN5321A3HN; HVQFN-40-1EP_6x6mm_P0.5mm_EP4.1x4.1mm
U8: MAX-M8Q; ublox_MAX
U9: MASW-007221; SOT-363_SC-70-6
U10: BGA725L6; BGA725L6E6327
U11: TLV70018_SOT23-5; SOT-23-5
U12: TXB0102DCU; VSSOP-8_2.3x2mm_P0.5mm
U13: MCP23017x-x-SS; SSOP-28_5.3x10.2mm_P0.65mm
U14: TSOP382xx; Vishay_MINICAST-3Pin
U15: TP4056; SOIC-8-1EP_3.9x4.9mm_P1.27mm_EP2.41x3.3mm_ThermalVias
U16: PESD5V0L4UG,115; SOT65P210X110-5N; PARTREV 04
U17: AP2112K-3.3; SOT-23-5
U18: DW01A; SOT-23-6
U19: SX1262IMLTRT; QFN50P400X400X100-25N
U20: PE4259; SOT65P215X110-6N
Y1: 40MHz SMD 3225; Crystal_SMD_2016-4Pin_2.0x1.6mm
Y2: 26 MHz SMD; Crystal_SMD_2016-4Pin_2.0x1.6mm
Y4: 27.120 MHz; Crystal_SMD_2016-4Pin_2.0x1.6mm
Y5: 32 MHz SMD; Crystal_SMD_2016-4Pin_2.0x1.6mm

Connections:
12C_SDA: J2.12, U13.13 (SDA)
+1V8: C84.1, C85.1, C86.1, C96.1, C97.1, C98.1, C100.1, R23.1, U8.7 (VCC_IO), U8.8 (VCC), U8.14 (VCC_RF), U11.5 (OUT), U12.3 (VCCA)
+5V: C104.1, D2.1 (K), D3.1 (K), D4.1 (K), D4.2 (A), P2.A4 (VBUS), P2.A9 (VBUS), P2.B4 (VBUS), P2.B9 (VBUS), Q2.6, Q2.7, R34.1, R39.1, TP3.1 (1_1), U15.4 (V_{CC}), U15.8 (CE), U17.1 (VIN), U18.2 (CS)
BOOT_BTN: R_BOOT1.2, SW1.2, TP5.1 (1_1), U1.5 (GPIO0)
BTN_DOWN: SW6.1, U1.21 (XTAL_32K_P)
BTN_LEFT: SW7.1, U1.47 (MTDI)
BTN_OK: SW4.1, U1.6 (GPIO1)
BTN_POWER: SW3.1, U1.28 (SPICS1)
BTN_RIGHT: SW8.1, U1.48 (MTMS)
BTN_UP: SW5.1, U1.7 (GPIO2)
CC1101_GDO0: U1.10 (GPIO5), U3.6 (GDO0)
CC1101_GDO2: U1.9 (GPIO4), U3.3 (GDO2)
CS_CC1101: U1.13 (GPIO8), U3.7 (NCS)
CS_PN532: U1.41 (GPIO36), U7.27 (NSS/P50_SCL/HSU_RX)
CS_SX1262: U1.38 (GPIO33), U19.19 (NSS)
DISP_BL: J2.11, U13.24 (GPA3)
DISP_CS: J2.8, U13.21 (GPA0)
DISP_DC: J2.9, U13.22 (GPA1)
DISP_MISO: J2.4, U1.32 (SPICS0)
DISP_MOSI: J2.5, R3.2
DISP_RST: J2.10, U13.23 (GPA2)
DISP_SCK: J2.6, U13.25 (GPA4)
DISP_SD_CS: J2.7, U13.26 (GPA5)
EN_BTN: C_EN1.1, R_EN1.2, SW2.2, TP10.1 (1_1), U1.4 (CHIP_PU)
FLASH_CLK: U1.17 (GPIO12), U2.6 (CLK)
FLASH_CS: U1.15 (GPIO10), U2.1 (~CS)
FLASH_IO0: U1.16 (GPIO11), U2.5 (DI/IO_{0})
FLASH_IO1: U1.18 (GPIO13), U2.2 (DO/IO_{1})
FLASH_IO2: U1.19 (GPIO14), U2.3 (~WP/IO_{2})
FLASH_IO3: U1.14 (GPIO9), U2.7 (~HOLD/~RESET/IO_{3})
GND: C1.2, C2.2, C3.2, C4.2, C5.2, C6.2, C7.2, C8.2, C9.2, C10.2, C11.2, C12.2, C13.2, C14.2, C15.2, C16.2, C17.2, C18.2, C19.1, C20.1, C23.1, C24.2, C25.2, C28.1, C67.1, C68.1, C69.1, C70.1, C71.1, C72.2, C73.1, C74.1, C75.1, C76.2, C77.1, C79.1, C81.2, C82.2, C84.2, C85.2, C86.2, C87.2, C88.2, C90.1, C93.2, C94.2, C95.2, C96.2, C97.2, C98.2, C99.2, C100.2, C101.2, C102.2, C103.2, C104.2, C106.2, C107.2, C108.2, C109.2, C110.2, C111.2, C112.2, C114.2, C115.2, C116.2, C118.2, C120.1, C121.1, C122.2, C124.1, C125.1, C_EN1.2, D1.2 (A2), FB2.2, FL1.2 (GND), FL1.4 (GND), FL1.5 (GND), J2.3, P1.2, P2.A1 (GND), P2.A12 (GND), P2.B1 (GND), P2.B12 (GND), Q1.2 (E), Q2.2, Q2.3, R7.1, R24.2, R33.1, R40.2, R_G45.2, R_G46.2, R_I1.1, SW1.1, SW2.1, TP4.1 (1_1), U1.57 (GND), U2.4 (GND), U3.16 (GND1), U3.19 (GND2), U3.DAP (GND3), U7.1 (DVSS), U7.3 (TVSS1), U7.7 (TVSS2), U7.11 (AVSS), U7.18 (TESTEN), U7.41 (AVSS), U8.1 (GND), U8.10 (GND), U8.12 (GND), U9.2 (GND), U10.1 (GND@1), U10.4 (GND@4), U11.2 (GND), U12.2 (GND), U13.10 (V_{SS}), U13.15 (A0), U13.16 (A1), U13.17 (A2), U14.2 (GND), U15.3 (GND), U15.9 (EPAD), U16.2, U17.2 (GND), U18.6 (GND), U19.2 (GND), U19.5 (GND), U19.8 (GND), U19.20 (GND), U19.25 (GND), U20.2 (GND), Y1.2 (GND), Y2.2 (GND)
GPIO45_STRAP: R_G45.1, U1.51 (GPIO45)
GPIO46_STRAP: R_G46.1, U1.52 (GPIO46)
GPS_EXTINT: U1.42 (GPIO37), U8.5 (EXTINT)
GPS_RESET: R23.2, U1.8 (GPIO3), U8.9 (~RESET)
GPS_RXD: TP9.1 (1_1), U1.50 (U0RXD), U12.8 (B1)
GPS_RX_1V8: U8.3 (RXD), U12.4 (A2)
GPS_SAFEBOOT: R27.2, U1.43 (GPIO38), U8.18 (~SAFEBOOT)
GPS_SCL: U1.12 (GPIO7), U8.17 (SCL)
GPS_SDA: U1.11 (GPIO6), U8.16 (SDA)
GPS_TIMEPULSE: U1.27 (GPIO21), U8.4 (TIMEPULSE)
GPS_TXD: R6.2, U12.1 (B2)
GPS_TX_1V8: U8.2 (TXD), U12.5 (A1)
I2C_SCL: J2.13, U1.36 (SPICLK_N), U13.12 (SCL)
I2C_SDA: U1.37 (SPICLK_P)
IR_RX: R5.2, U14.1 (OUT)
IR_TX: R4.2, R31.1, TP7.1 (1_1)
unnamed: AE1.1, C78.2, C79.2
unnamed: AE1.2, C80.2, C81.1
unnamed: C3.1, L1.2, U1.2 (VDD3P3), U1.3 (VDD3P3)
unnamed: C13.1, C14.1, L3.2, L4.1
unnamed: C21.1, C23.2, L5.2, L6.1
unnamed: C21.2, C22.1, L7.2, L8.2
unnamed: C22.2, L6.2, L9.1
unnamed: C24.1, L8.1
unnamed: C25.1, L9.2, L10.1
unnamed: C26.1, C27.1, L10.2
unnamed: C27.2, L11.1
unnamed: C76.1, C78.1, L25.2
unnamed: C77.2, C80.1, L26.2, R21.2
unnamed: C83.2, R21.1
unnamed: C91.2, FB1.2
unnamed: C105.1, L27.2
unnamed: C113.1, C114.1, L29.1, L30.2, L31.1
unnamed: C113.2, C115.1, C117.1, L31.2
unnamed: C117.2, L32.1
unnamed: C123.2, C124.2, L34.1
unnamed: C26.2, CC1101_ANT1.1 (A_1), L11.2
unnamed: C15.1, D1.1 (A1), L4.2, PCB_ANT1.1 (A_1)
unnamed: D2.2 (A), R35.1
unnamed: D3.2 (A), R36.1
unnamed: FB1.1, R25.1
unnamed: FL1.1 (IN), U10.3 (AO)
unnamed: C92.2, FL1.3 (OUT)
unnamed: GPS_ANT1.1 (A_1), L27.1
unnamed: IR_LEDs1.2 (A), R30.1
unnamed: IR_LEDs1.1 (K), IR_LEDs2.1 (K), IR_LEDs3.1 (K), Q1.3 (C)
unnamed: IR_LEDs2.2 (A), R29.1
unnamed: IR_LEDs3.2 (A), R32.1
unnamed: JP1.1 (A), U8.13 (LNA_EN)
unnamed: JP1.2 (B), R24.1, U9.4 (V2)
unnamed: L25.1, R20.2
unnamed: L26.1, R22.2
unnamed: P2.A5 (CC), P2.B5 (VCONN), R40.1
unnamed: P2.A6 (D+), U16.1
unnamed: P2.A7 (D-), U16.3
unnamed: FB2.1, P2.SH (SHIELD)
unnamed: Q1.1 (B), R31.2
unnamed: Q2.1, Q2.8
unnamed: R37.1, SW3.2
unnamed: R38.1, SW4.2
unnamed: R41.1, SW5.2
unnamed: R42.1, SW6.2
unnamed: R43.1, SW7.2
unnamed: R44.1, SW8.2
unnamed: C125.2, L34.2, SX1262.1 (A_1)
unnamed: C12.1, L3.1, U1.1 (LNA_IN)
unnamed: R3.1, U1.33 (SPICLK)
unnamed: R2.1, U1.35 (SPID)
unnamed: R5.1, U1.30 (SPIHD)
unnamed: R1.1, U1.34 (SPIQ)
unnamed: R4.1, U1.31 (SPIWP)
unnamed: C11.1, U1.53 (XTAL_N), Y1.3 (XOUT)
unnamed: L2.2, U1.54 (XTAL_P)
unnamed: C18.1, U3.5 (DCOUPL)
unnamed: R7.2, U3.17 (RBIAS)
unnamed: L7.1, U3.13 (RF_N)
unnamed: L5.1, U3.12 (RF_P)
unnamed: C19.2, U3.8 (XOSC_Q1), Y2.1 (XIN)
unnamed: C20.2, U3.10 (XOSC_Q2), Y2.3 (XOUT)
unnamed: C70.2, U7.8 (AVDD)
unnamed: C67.2, U7.39 (DVDD)
unnamed: R_I0.2, U7.16 (I0)
unnamed: R_I1.2, U7.17 (I1)
unnamed: C73.2, U7.14 (OSCIN), Y4.2
unnamed: C74.2, U7.15 (OSCOUT), Y4.1
unnamed: R18.2, U7.32 (P32_INT0)
unnamed: C83.1, U7.10 (RX)
unnamed: R19.1, U7.34 (SIC_CLK/P34)
unnamed: C75.2, U7.37 (SVDD)
unnamed: C69.2, U7.5 (TVDD)
unnamed: R20.1, U7.4 (TX1)
unnamed: R22.1, U7.6 (TX2)
unnamed: C82.1, U7.9 (VMID)
unnamed: C89.1, U8.11 (RF_IN)
unnamed: C88.1, U8.6 (V_BCKP)
unnamed: C91.1, U9.1 (RF1)
unnamed: C92.1, U9.3 (RF2)
unnamed: C89.2, U9.5 (RFC)
unnamed: C105.2, U10.5 (AI)
unnamed: R26.2, U11.3 (EN)
unnamed: R28.2, U12.6 (OE)
unnamed: R45.2, U13.18 (~RESET)
unnamed: R33.2, U15.2 (PROG)
unnamed: R34.2, U15.1 (TEMP)
unnamed: R35.2, U15.7 (~CHRG)
unnamed: R36.2, U15.6 (~STDBY)
unnamed: R39.2, U17.3 (EN)
unnamed: Q2.5, U18.3 (OC)
unnamed: Q2.4, U18.1 (OD)
unnamed: L28.1, U19.9 (DCC_SW)
unnamed: C119.1, L33.2, U19.22 (RFI_N)
unnamed: C121.2, L33.1, U19.21 (RFI_P)
unnamed: L30.1, U19.23 (RFO)
unnamed: C110.1, L28.2, U19.7 (VREG)
unnamed: C111.1, C112.1, L29.2, U19.24 (VR_PA)
unnamed: U19.3 (XTA), Y5.2
unnamed: U19.4 (XTB), Y5.1
unnamed: C122.1, R48.2, U20.4 (CTRL)
unnamed: C118.1, L32.2, U20.1 (RF1)
unnamed: C119.2, C120.2, U20.3 (RF2)
unnamed: C123.1, U20.5 (RFC)
unnamed: C116.1, R47.2, U20.6 (~CTRL/VDD)
unnamed: C10.1, L2.1, Y1.1 (XIN)
PN532_IRQ: U1.40 (GPIO35), U7.25 (P70_IRQ)
PN532_RESET: R_38.2, U1.39 (GPIO34), U7.38 (~RSTPD)
SPI_MISO: U1.24 (GPIO18), U3.2 (SO/GDO1), U7.29 (MISO/P71), U19.16 (MISO)
SPI_MOSI: U1.22 (XTAL_32K_N), U3.20 (SI), U7.28 (MOSI/SDA/HSU_TX), U19.17 (MOSI)
SPI_SCK: U1.23 (GPIO17), U3.1 (SCLK), U7.30 (SCK/P72), U19.18 (SCK)
SX1262_BUSY: R1.2, U19.14 (BUSY)
SX1262_DIO1: U1.44 (MTCK), U19.13 (DIO1)
SX1262_DIO2: R2.2, R48.1, U19.12 (DIO2)
SX1262_RESET: R46.1, U1.45 (MTDO), U19.15 (~RESET)
TOUCH_IRQ: J2.14, U13.27 (GPA6)
TOUCH_RST: J2.15, U13.28 (GPA7)
TP_BAT: C101.1, P1.1, TP2.1 (1_1), U15.5 (BAT), U18.5 (VCC)
TP_UART_TX: R6.1, TP8.1 (1_1), U1.49 (U0TXD)
USB_DN: U1.25 (GPIO19/USB_D-), U16.4
USB_DP: U1.26 (GPIO20/USB_D+), U16.5
VDD33: C1.1, C2.1, C4.1, C5.1, C6.1, C7.1, C8.1, C9.1, C16.1, C17.1, C28.2, C68.2, C71.2, C72.1, C87.1, C90.2, C93.1, C94.1, C95.1, C99.1, C102.1, C103.1, C106.1, C107.1, C108.1, C109.1, J2.1, J2.2, L1.1, R18.1, R19.2, R25.2, R26.1, R27.1, R28.1, R29.2, R30.2, R32.2, R37.2, R38.2, R41.2, R42.2, R43.2, R44.2, R45.1, R46.2, R47.1, R_38.1, R_BOOT1.1, R_EN1.1, R_I0.1, TP1.1 (1_1), U1.20 (VDD3P3_RTC), U1.29 (VDD_SPI), U1.46 (VDD3P3_CPU), U1.55 (VDDA), U1.56 (VDDA), U2.8 (VCC), U3.4 (DVDD), U3.9 (AVDD1), U3.11 (AVDD2), U3.14 (AVDD3), U3.15 (AVDD4), U3.18 (DGUARD), U7.23 (PVDD), U7.40 (VBAT), U9.6 (V1), U10.2 (VCC), U10.6 (PON), U11.1 (IN), U12.7 (VCCB), U13.9 (V_{DD}), U14.3 (Vs), U17.5 (VOUT), U19.1 (VDD_IN), U19.10 (VBAT), U19.11 (VBAT_IO)

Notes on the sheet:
ESD Protection
MicroController, (ESP32 S3 die) raw chip
TLV70018 (1.8V LDO)
TP4056
GPS subsystem - three components treated as one
GPIO 47
GPIO 48
DISPLAY
USB-C connector
Micro SD Card
CC1101 - Sub-GHz Transceiver
TXB0102
PN532 - NFC / RFID Controller
EXTRA GPIOs
SX1262 - LoRa Transceiver
POWER SYSTEM
MAX-M8Q GPS
AP2112K
W25Q128 (External SPI Flash)
BUTTON
IR TX / RX
Test Points

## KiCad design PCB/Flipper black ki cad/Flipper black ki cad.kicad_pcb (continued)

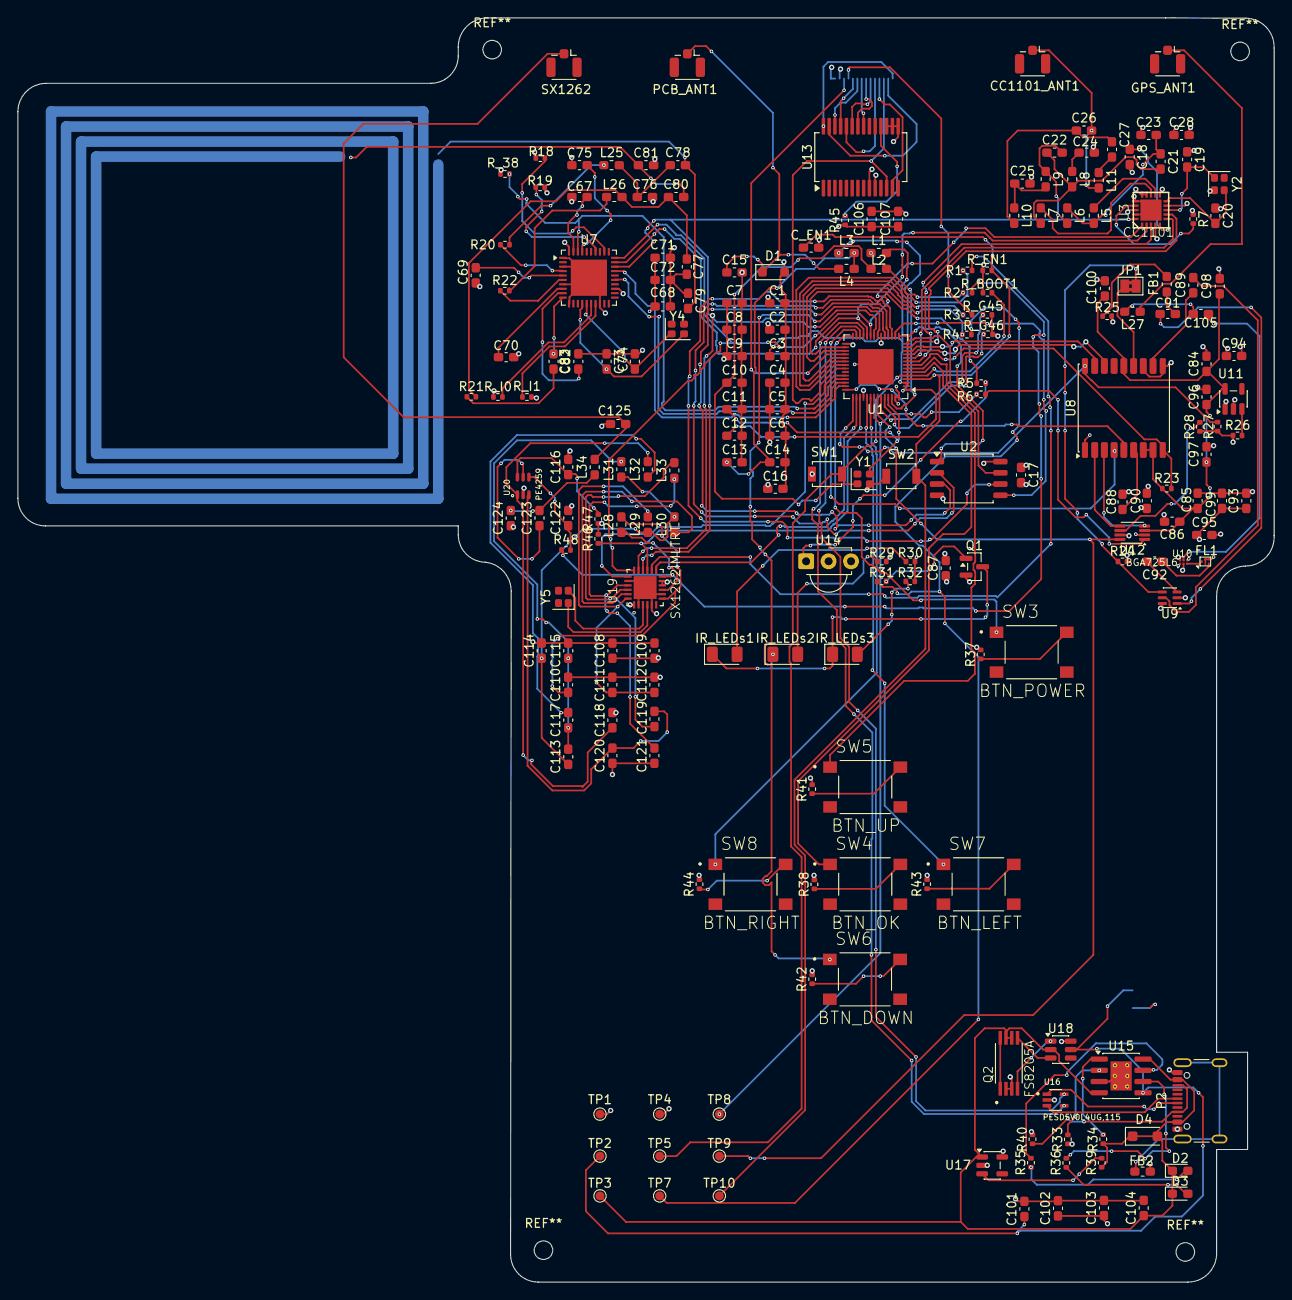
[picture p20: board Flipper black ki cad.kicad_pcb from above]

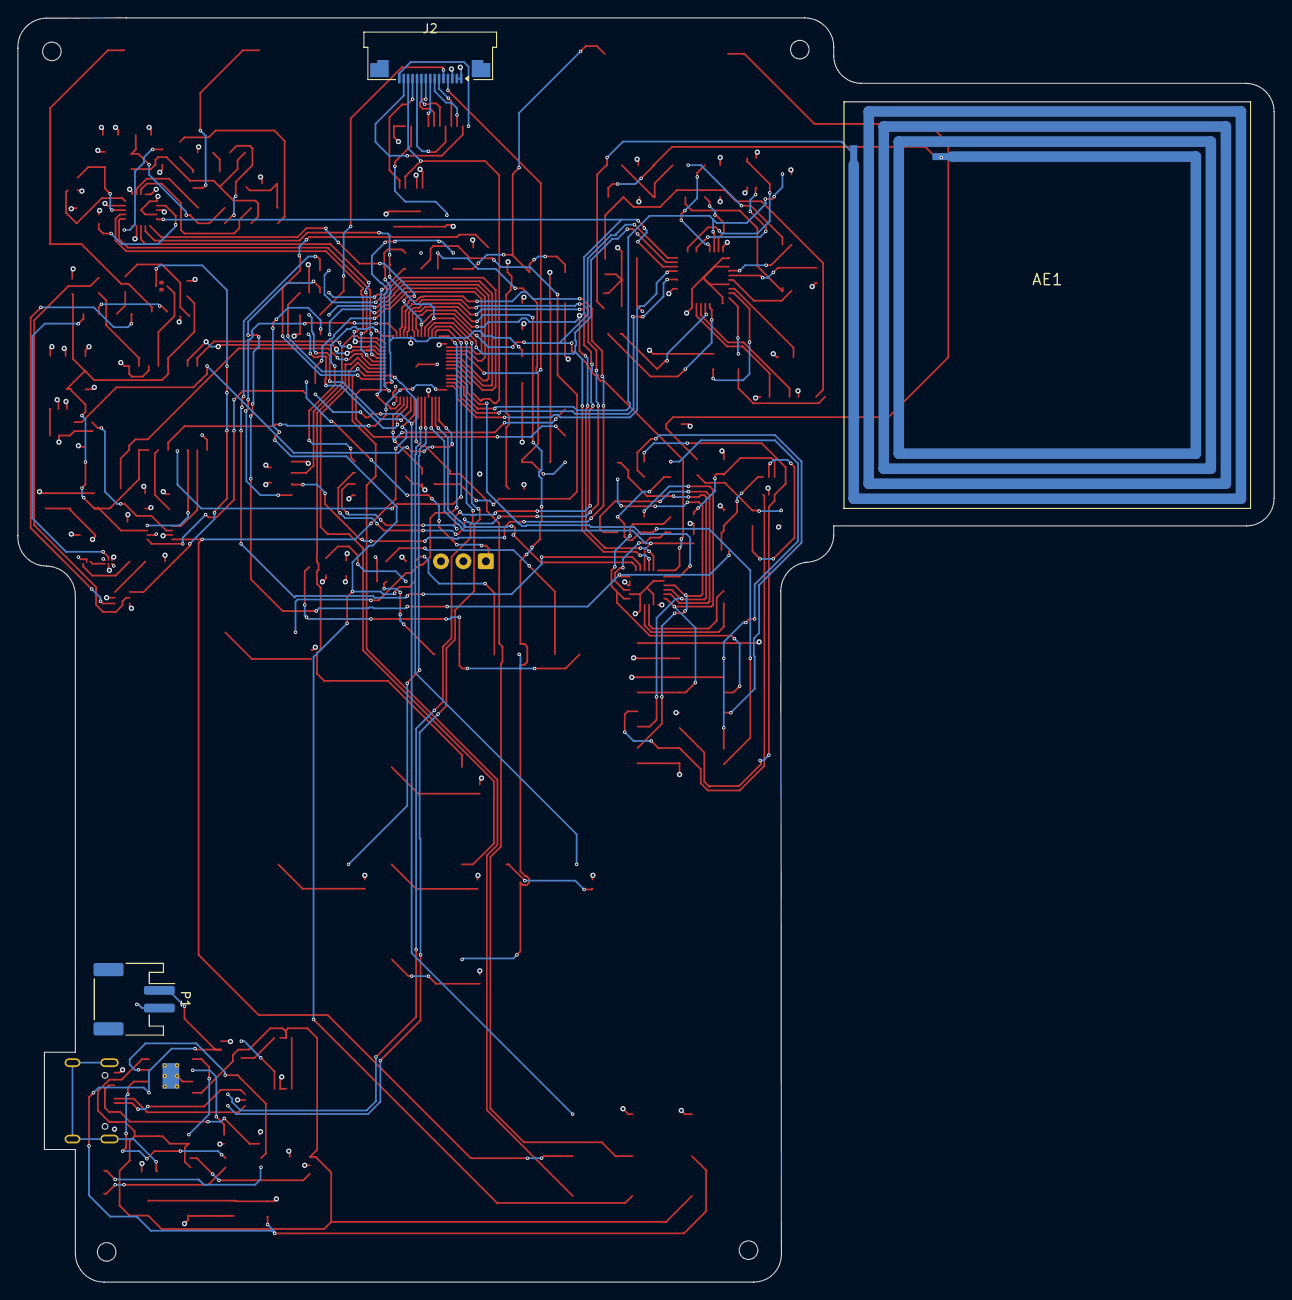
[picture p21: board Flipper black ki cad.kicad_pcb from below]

Board: 4 copper layers, 142.1 x 143.0 mm, 213 parts (3 on the bottom side), 169 nets.

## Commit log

2026-05-16 guide added
    [Flipper black ki cad.kicad_sch]
2026-05-16 Create ~Flipper black ki cad.kicad_pro.lck
2026-05-17 les goo
    [Flipper black ki cad.kicad_sch]
2026-05-17 i more done
    [Flipper black ki cad.kicad_sch]
2026-05-18 lets gooo
    [Flipper black ki cad.kicad_sch]
2026-05-18 almost SCH done
    [Flipper black ki cad.kicad_sch]
2026-05-19 Create Flipper black ki cad-2026-05-19_231004.zip
2026-05-19 more more more
    [Flipper black ki cad.kicad_sch]
2026-05-21 no finally
    [Flipper black ki cad.kicad_sch]
2026-05-22 agg aggg
    [Flipper black ki cad.kicad_sch]
2026-05-28 zeeeee
    yayaya
    [Flipper black ki cad.kicad_pcb, Flipper black ki cad.kicad_sch]
2026-05-30 Big update - description of changes
    [Upper body.step, full step file_.step, lower body.step]
2026-06-01 Rename project to 'Flipper Black' and update details
    Updated project name and description in README.md to reflect new branding and features of the Flipper Black device.
2026-06-24 Add assembly section to README
    Added assembly instructions for the enclosure.
2026-07-17 Create Flipper black ki cad-2026-07-15_161637.zip
2026-07-17 Create Flipper black ki cad-2026-07-15_161658.zip
2026-07-17 Update Flipper black ki cad.kicad_pcb
2026-07-17 Update Flipper black ki cad.kicad_prl
2026-07-26 Fix image formatting in CAD n Assembly section
2026-07-26 Add PCB section with 3D model image

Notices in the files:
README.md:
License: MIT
